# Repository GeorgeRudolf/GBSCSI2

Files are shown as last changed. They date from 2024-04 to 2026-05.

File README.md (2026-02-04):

# GBSCSI2
Affordable SCSI Disk Emulator - upgrade over the original GBSCSI

NOTE: Above all, these boards were initially designed as a hack to satisfy my own personal needs. With that said, they've been tested fairly extensively. Please read this entire README.

Herein are the design files for all variants of GBSCSI2 in KiCad 7 format, being migrated to KiCad 9. The hardware in this repository is licensed CERN OHL-S V2, the full terms of which can be found at https://ohwr.org/cern_ohl_s_v2.pdf and https://ohwr.org/cern_ohl_s_v2.txt.

With thanks to [The Decromancer](https://decromancer.ca/) for sponsoring this project; wohali, tr0n, compu85, sabur and luigi30 for testing; and the rest of UHF for their continued enthusiasm and support. Also to [Rabbit Hole Computing](https://www.rabbitholecomputing.com/) for their continued maintenance of the ZuluSCSI firmware that makes these boards complete, and further testing and collaboration on this project.

# HOW TO:
1. Buy board from decromancer or [Emmy Bear Retro](https://retro.emmybear.shop)
2. It arrives at your doorstep ready to use

OR

1. Get assembled boards using the files in this repository
2. Solder header of your choice
3. (Except for RP2040 version, or if ordering Pico from JLC) Solder RPi Pico - use Pico-W if you want DaynaPORT capabilities for a Mac
4. Go to https://github.com/ZuluSCSI/ZuluSCSI-firmware and grab the Pico/Pico_DaynaPORT version of the latest release and flash to the board by connecting via USB while holding BOOTSEL (or toggling the boot dip switch for RP2040)

# The (very important) details:

1. GBSCSI2 is being moved to a revised hierarchical design that allows for modularity and ease of customization, while maintaining uniformity. The whole project is considered WIP - this warning will be removed once things are tested. Previous versions have been moved to an archive folder. More about them below.

2. The archived Wide SCSI variants are BROKEN. They're incomplete and not usable. 
Rabbit Hole Computing has forked these designs, corrected their flaws and finished the implementation in a manner compatible with standard ZuluSCSI firmware. This fork is now available at https://github.com/ZuluSCSI/ZuluSCSI-Ultra-Wide-OSHW-RP2350B.

3. The variants tagged "untested" are exactly that. I've never personally made boards from them. Use at your own risk.

4. For changes and errata, see the relevant files in the repo.

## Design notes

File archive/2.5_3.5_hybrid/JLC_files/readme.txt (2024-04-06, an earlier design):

JLC RPi Pico pricing is less than ideal - when presented with checkboxes for each component type, you can uncheck the Pico and install your own when boards arrive. Or, leave checked and enjoy the commodity of having them assemble it for you for a few extra bucks.

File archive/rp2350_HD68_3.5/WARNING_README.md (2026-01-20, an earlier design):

This design is incomplete and not usable. Do not manufacture boards from it.

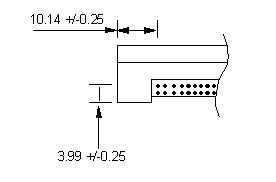
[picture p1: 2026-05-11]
CAD/25mec1.gif

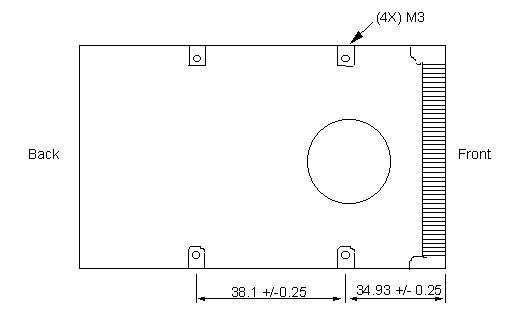
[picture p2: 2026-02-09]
CAD/wds2mec2.gif

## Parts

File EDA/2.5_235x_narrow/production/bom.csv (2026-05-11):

Designator | Footprint | Quantity | Value | LCSC Part #
C1, C4 | 0603 | 2 | 4.7μF | C19666
C10, C27, C5 | 0402 | 3 | 4.7μF | C23733
C11, C13, C14, C15, C16, C17, C18, C19, C28, C6, C8, C9 | 0402 | 12 | 100nF | C307331
C12 | 0402 | 1 | 1μF | C52923
C2, C3 | 0402 | 2 | 15pF | C1548
C20, C35 | 1206 | 2 | 47μF | C96123
C21 | 0603 | 1 | 12pF | C38523
C22, C23, C24, C25, C26, C32, C33 | 0603 | 7 | 100nF | C14663
C29, C30, C7 | 0603 | 3 | 10μF | C96446
C31, C34 | 0603 | 2 | 1μF | C15849
D1, D2, D3, D4 | D_SOD-123 | 4 | 1N5819 | C82544
D5 | 0603 | 1 | YELLOW | C72038
F1, F2 | 0805 | 2 | 1A | C468888
FID1 | Fiducial_0.5mm_Mask1mm | 1 | Fiducial | N/A
J1 | PinHeader_2x25-2_P2.00mm_straddle | 1 | SCSI_50-2P_2mm | N/A
J1.1 | IDC-Header_2x25_P2.54mm_Horizontal | 1 | SCSI_50P_2.54mm | N/A
J2 | TF01A | 1 | TF003 | C5155563
J3 | USB_C_Receptacle_HRO_TYPE-C-31-M-12 | 1 | GCT-4105 | C2927038
J4 | JST_SH_SM03B-SRSS-TB_1x03-1MP_P1.00mm_Horizontal | 1 | SM03B-SRSS-TB | C160403
J4.1 | PinHeader_1x04_P2.54mm_Vertical | 1 | Conn_01x04 | N/A
J5 | PinHeader_1x04_P2.54mm_Horizontal | 1 | Conn_01x04 | N/A
J6 | PinHeader_1x02_P2.54mm_Vertical | 1 | Conn_01x02 | N/A
JP1, JP2 | PinHeader_2x01_P2.54mm_Vertical | 2 | Jumper_2_Open | N/A
L1 | L_Abracon_AOTA-B2016 | 1 | 3.3μH | C42411119
L2 | 1008 | 1 | 1μH | C5832356
M1 | RPi_RM2 | 1 | ~ | N/A
Q1, Q10, Q11, Q12, Q13, Q14, Q15, Q16, Q17, Q18, Q2, Q3, Q4, Q5, Q6, Q7, Q8, Q9 | SOT-23 | 18 | AO3401A | C15127
R1, R4 | 0402 | 2 | 1kΩ | C11702
R10, R11, R12, R18, R19, R20, R21, R22, R29, R5, R6, R7, R8, R9 | 0603 | 14 | 4.7kΩ | C23162
R13, R14, R17, R26, R27, R28, R30, R55 | 0603 | 8 | 1kΩ | C21190
R15, R16, R3 | 0402 | 3 | 22Ω | C25092
R2 | 0402 | 1 | 4.7kΩ | C25900
R23, R24 | 0402 | 2 | 5.1kΩ | C25905
R25, R31, R32, R33, R34, R35, R36, R37, R38, R39, R40, R41, R42, R43, R44, R45, R46, R47, R48 | 0603 | 19 | 110Ω | C22781
R49, R54 | 0402 | 2 | 10kΩ | C25744
R50 | 0402 | 1 | 442kΩ | C5101
R51 | 0402 | 1 | 100kΩ | C25741
R52 | 0603 | 1 | 0Ω | C21189
R53 | 0603 | 1 | ~ | N/A
R56 | 0402 | 1 | 470Ω
SW1 | SW_DIP_SPSTx04_Slide_6.7x11.72mm_W8.61mm_P2.54mm_LowProfile | 1 | SW_DIP_x04 | C5160841
U1 | RP2350-QFN-60-1EP_7x7_P0.4mm_EP3.4x3.4mm_ThermalVias | 1 | RP235x_60QFN | C41378174
U10 | SOT-223-3_TabPin2 | 1 | AZ1117-2.85 | C14791
U2 | SOIC-8_5.23x5.23mm_P1.27mm | 1 | W25Q128JVS | C97521
U3 | SOT-23-6 | 1 | USB TVS | C2827654
U4, U5 | SSOP-20_5.3x7.2mm_P0.65mm | 2 | 74LVTH245 | C2652121
U6, U7 | TSSOP-14_4.4x5mm_P0.65mm | 2 | 74LVTH125 | C7042
U8 | SOT-23-5 | 1 | SN74AHC1G125DBVR | C7468
U9 | SOT-23-5 | 1 | TLV62569DBV | C141836
Y1 | Crystal_SMD_3225-4Pin_3.2x2.5mm | 1 | 12MHz | C20625731

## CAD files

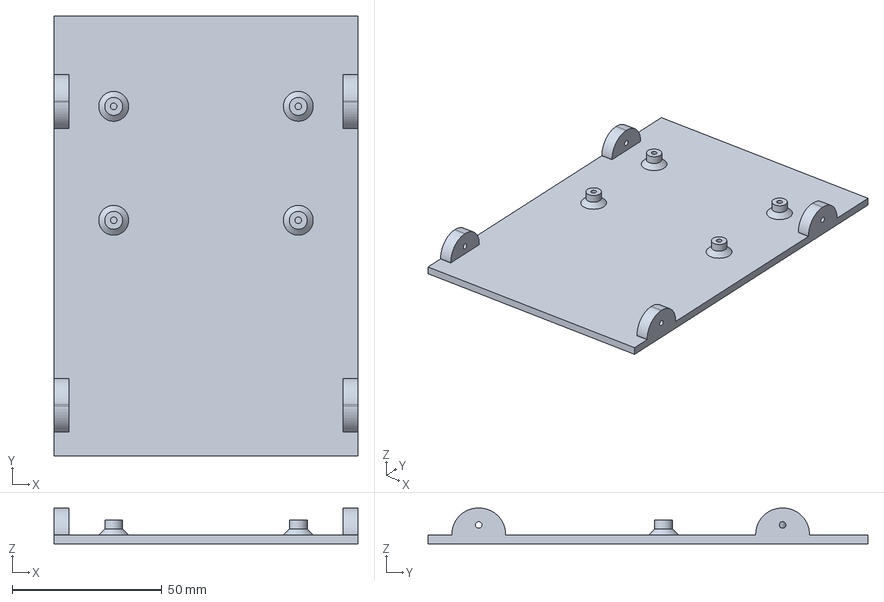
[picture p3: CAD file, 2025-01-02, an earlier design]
archive/2.5_3.5_hybrid/CAD/FreeCAD/GBSCSI2_OS.FCStd
101.7 x 147.0 x 12.0 mm

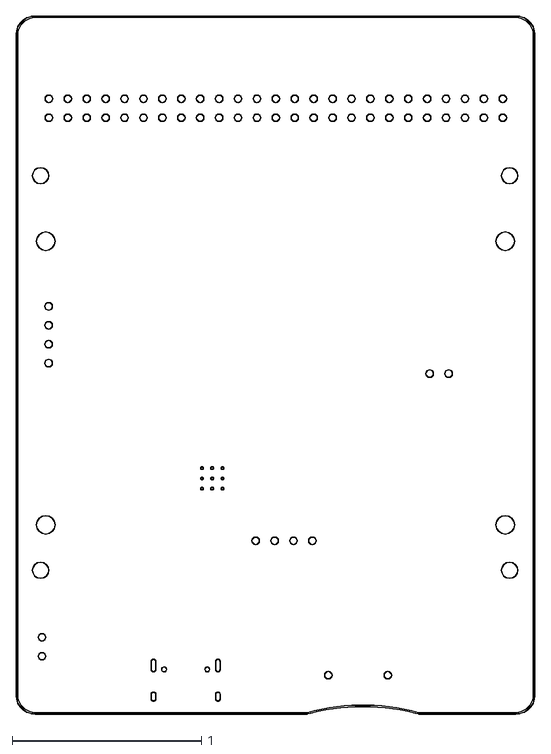
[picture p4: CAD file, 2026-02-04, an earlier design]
archive/rp2350_2.5_3.5_narrow/gbscsi2-Edge_Cuts.dxf
2.74 x 3.69

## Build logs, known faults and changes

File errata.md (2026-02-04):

1. v1.0b Hybrid and v1.0 RP2040 boards have the wrong pad deleted for keying pin on 2.5" header - should be 17 instead of 21.

Patch: Do not install/cut pin 17.

Change: Connector rekeyed.

2. Buck converter for 3.3V has too high of a VIN for the combined drops of all diodes in the 5V chain.

Patch: Lower Vf diodes can (and were) substituted as partial mitigation. Users with other needs would need to investigate their own solutions, potentially using an LM1117-3.3V regulator or similar.

Change: Redesign pending. (Jan/26)

3. Feb. 04 2026> Change: Migrated project to from-scratch redesign.

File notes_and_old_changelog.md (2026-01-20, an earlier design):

# Notes:
1. GBSCSI2 (as of January 2026) does not support powering from TERMPWR in systems with low Vtt. Use the 4-pin connector, with a Molex pigtail if necessary. Examples of machines which may present low Vtt are compact Macs, where TERMPWR is derived from the main 5V rail thru a 1N4001 diode (One can try to mitigate this by replacing the 1N4001 with a Schottky diode of lower Vf).
This exhibits a large forward voltage and may fail to meet SCSI spec. GBSCSI2 is designed with cost and power efficiency in mind, and as such, uses a cheap buck DC-DC converter to supply the board with 3.3V. Minimum input voltage as per the manufacturer's datasheet is 4.2V.
Given the forward voltage of the diodes on GBSCSI2 (about 450mV), and Vtt at TERMPWR having a minimum of 4.25V, this may leave the regulator receiving only about 3.8V. Feeding the regulator less than 4.0V has been reported to result in erratic operation. In that scenario, please power
the board from a separate 5V source as described above. If there is enough demand, a variant employing an LDO can be created. This would, however, waste more power, which is undesirable in laptops - the main use case for which this board was created. A redesign is pending.

2. JLC will no longer solder the Pico for you using their Economic PCBA service. The Standard PCB service has a $25 setup fee. Their Pico prices are not great anyway, so you might as well also solder that on your own, if you wanna save as much as possible. 

# Changelog:
1. PDN redesigned on Hybrid V1.0 boards to provide better ground return paths. V1.0b implements the change and is the first publicly available variant in this repository.

2. v1.0c Hybrid changed to 1.0d, for ground plane repour around 2.5" header keying change in 1.0c. Other 2.5" boards also changed, but as they don't have published gerbers, their revision numbers weren't changed.
Schottky diodes changed in BoM for all boards (JLC P/N C8598 to C82544). This is due to C8598 typically exhibiting too high of a forward voltage.

3. RP2350 boards have been tested by Rabbit Hole Computing's (makers of ZuluSCSI) Alex Perez (many thanks!) and are officially released as validated builds. Suitable firmware available at https://github.com/ZuluSCSI/ZuluSCSI-firmware/releases/tag/v2024.10.11-pico2-beta

4. A Fast Wide SCSI variant was been designed, and abandoned for the entirety of 2025. As of January 2026, the files in the repository are unusable for practical purposes as-is. A redesign is pending.

5. Further changes will no longer be logged here, but in commit history alone. Critical errata will be listed separately.

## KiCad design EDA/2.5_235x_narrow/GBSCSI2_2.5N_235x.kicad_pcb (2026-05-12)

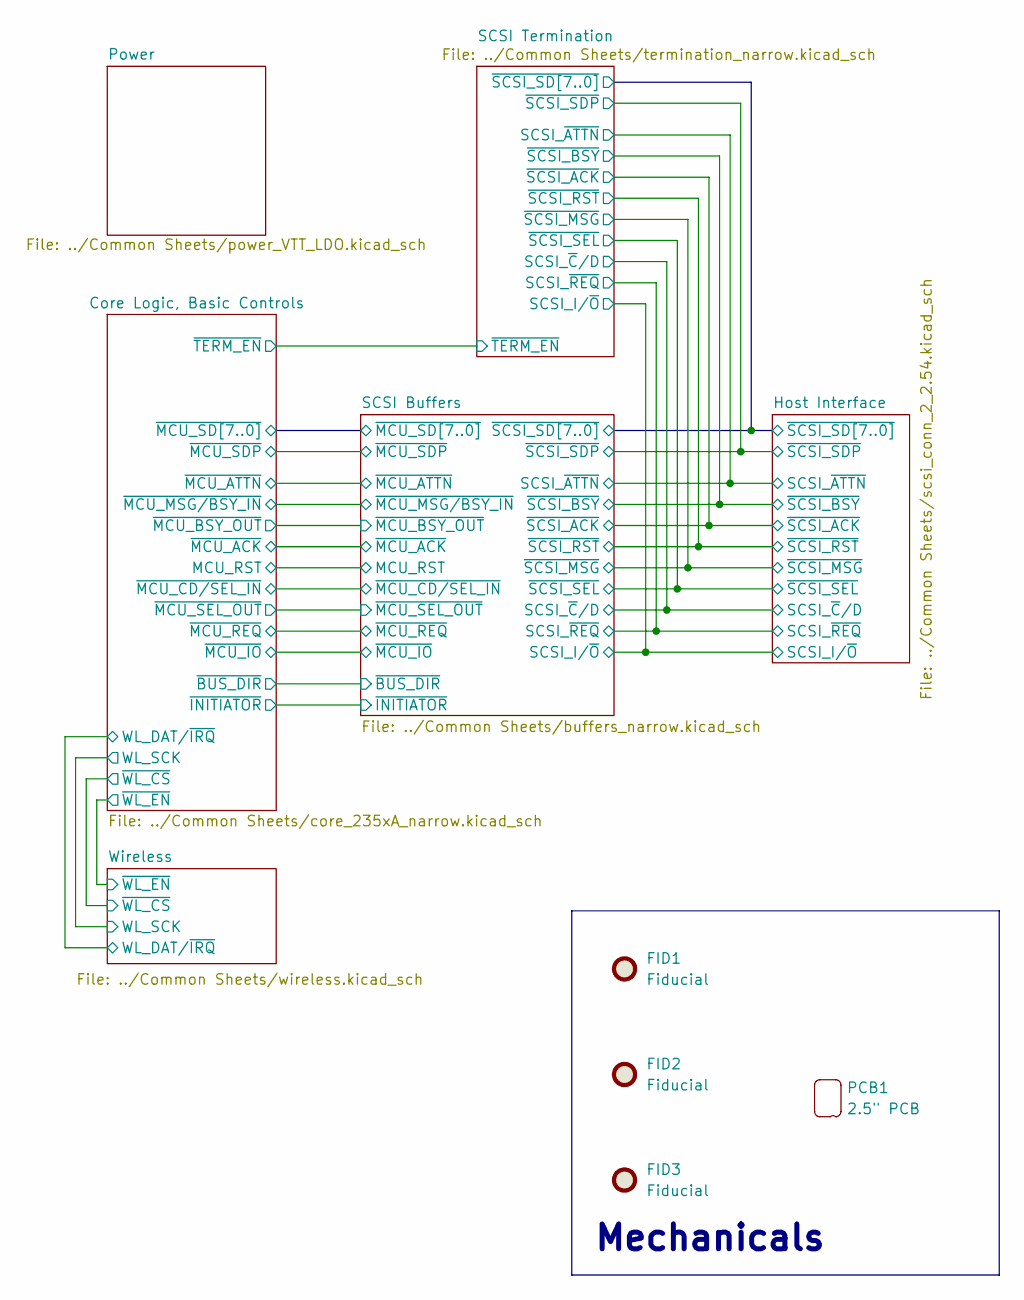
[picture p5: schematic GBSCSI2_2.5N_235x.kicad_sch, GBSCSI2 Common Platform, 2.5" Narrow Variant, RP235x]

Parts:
FID1, FID2, FID3: Fiducial; Fiducial_0.5mm_Mask1mm; LCSC N/A
PCB1: 2.5" PCB; GBSCSI2_2.5_PCB

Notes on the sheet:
Mechanicals

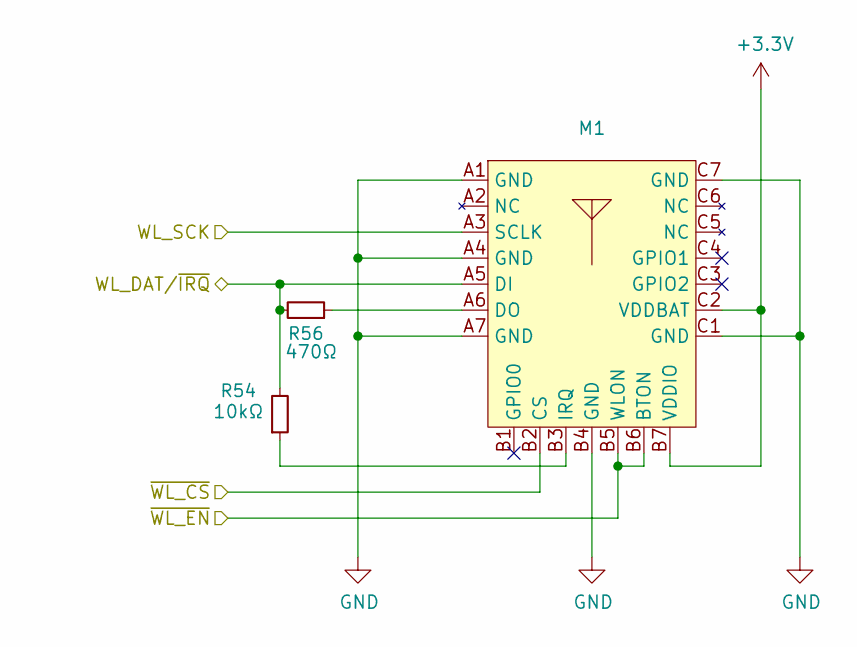
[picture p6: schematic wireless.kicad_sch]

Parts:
M1: RPi_RM2; LCSC N/A
R54: 10kΩ; R_0402_1005Metric; LCSC C25744
R56: 470Ω; R_0402_1005Metric

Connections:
+3.3V: M1.B7 (VDDIO), M1.C2 (VDDBAT); also elsewhere on the board
/Core Logic, Basic Controls/WL_DAT/~IRQ: M1.A5 (DI), R54.2, R56.2; also elsewhere on the board
/Core Logic, Basic Controls/WL_SCK: M1.A3 (SCLK); also elsewhere on the board
/Core Logic, Basic Controls/~WL_CS: M1.B2 (CS); also elsewhere on the board
/Core Logic, Basic Controls/~WL_EN: M1.B5 (WLON), M1.B6 (BTON); also elsewhere on the board
GND: M1.A1 (GND), M1.A4 (GND), M1.A7 (GND), M1.B4 (GND), M1.C1 (GND), M1.C7 (GND); also elsewhere on the board
unnamed: M1.A6 (DO), R56.1
unnamed: M1.B3 (IRQ), R54.1

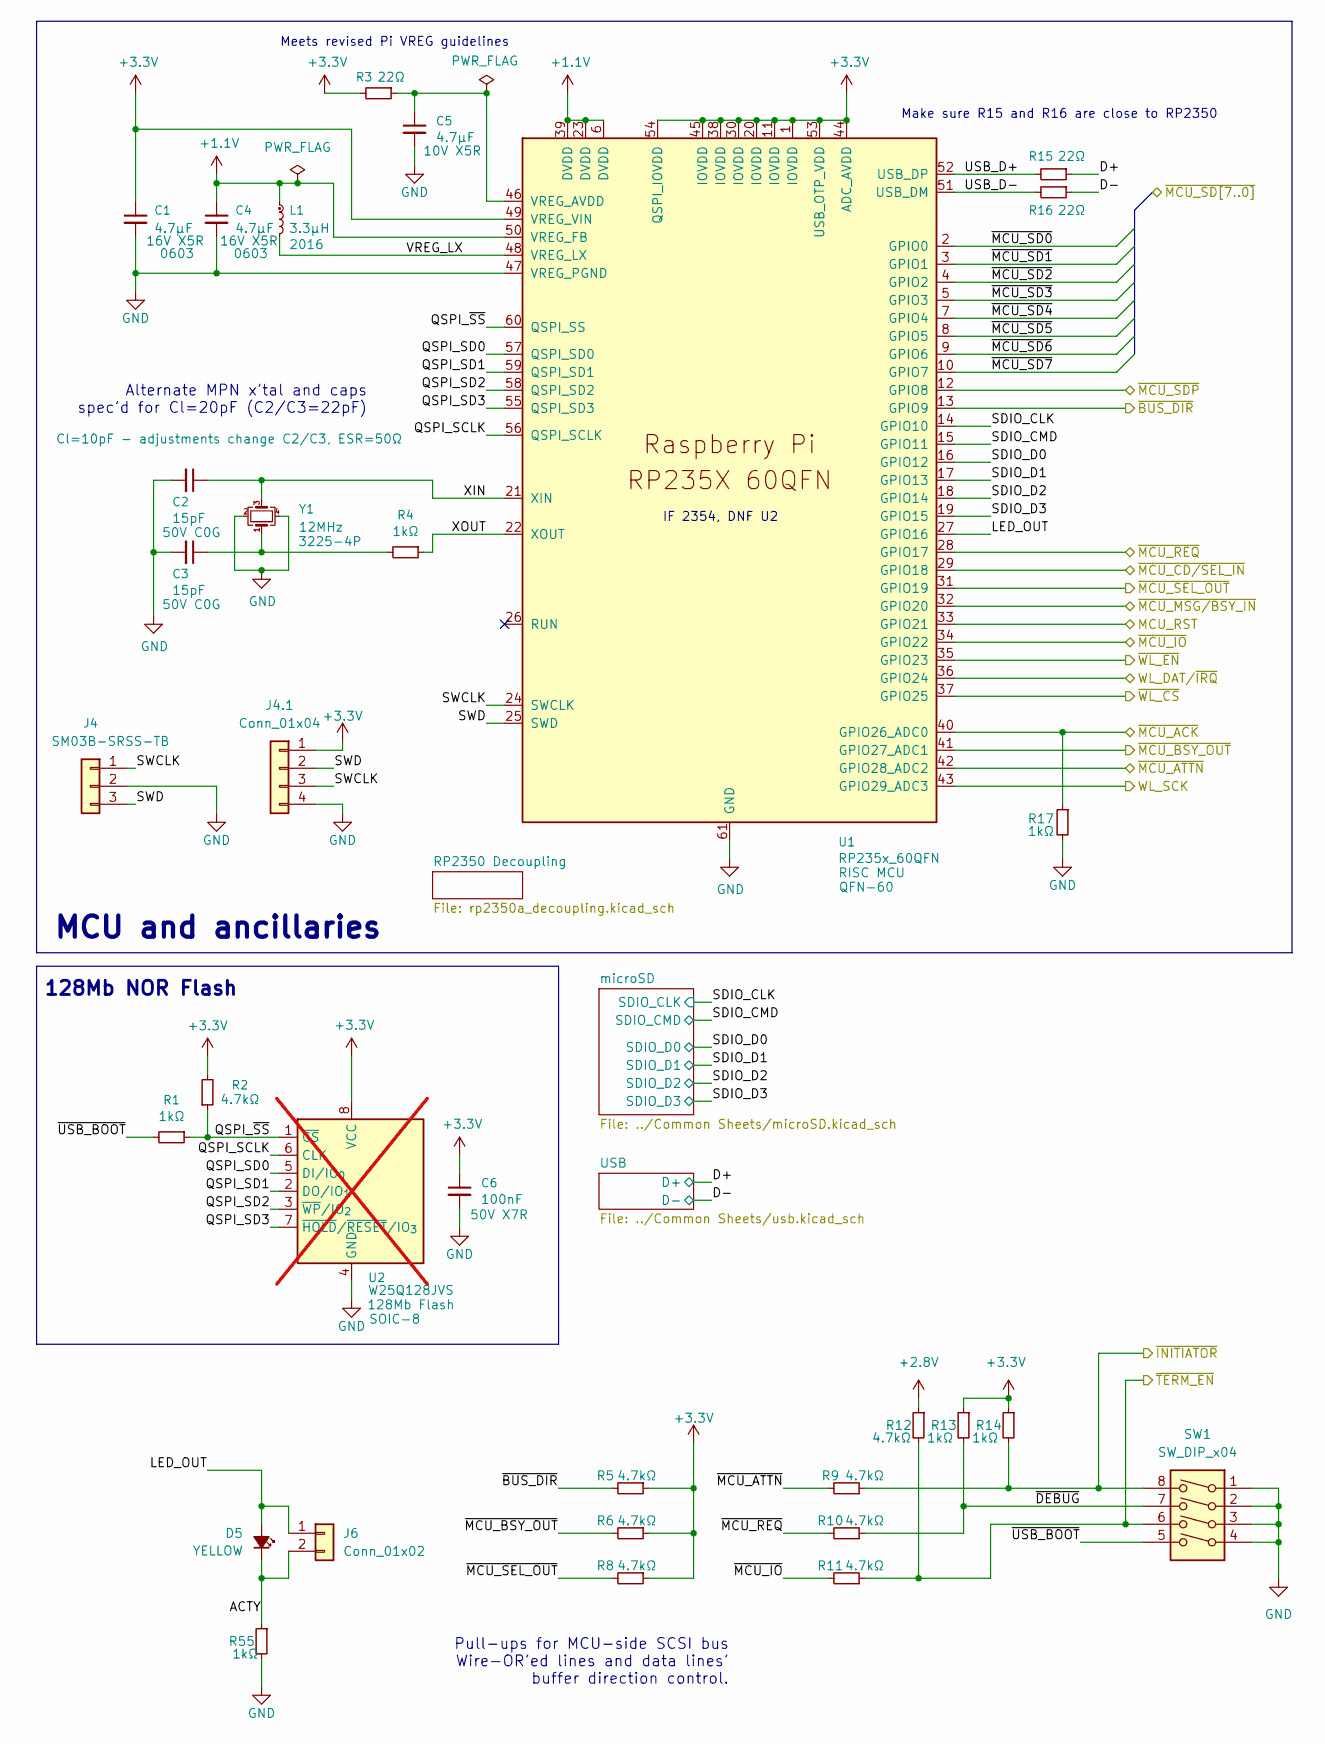
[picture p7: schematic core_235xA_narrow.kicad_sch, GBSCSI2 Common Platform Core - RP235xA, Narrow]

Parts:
C1, C4: 4.7μF; C_0603_1608Metric; LCSC C19666
C2, C3: 15pF; C_0402_1005Metric; LCSC C1548
C5: 4.7μF; C_0402_1005Metric; LCSC C23733
C6: 100nF; C_0402_1005Metric; LCSC C307331
D5: YELLOW; LED_0603_1608Metric; LCSC C72038
J4: SM03B-SRSS-TB; JST_SH_SM03B-SRSS-TB_1x03-1MP_P1.00mm_Horizontal; LCSC C160403
J4.1: Conn_01x04; PinHeader_1x04_P2.54mm_Vertical; LCSC N/A
J6: Conn_01x02; PinHeader_1x02_P2.54mm_Vertical; LCSC N/A
L1: 3.3μH; L_Abracon_AOTA-B2016; LCSC C42411119
R1, R4: 1kΩ; R_0402_1005Metric; LCSC C11702
R2: 4.7kΩ; R_0402_1005Metric; LCSC C25900
R3, R15, R16: 22Ω; R_0402_1005Metric; LCSC C25092
R5, R6, R8, R9, R10, R11, R12: 4.7kΩ; R_0603_1608Metric; LCSC C23162
R13, R14, R17, R55: 1kΩ; R_0603_1608Metric; LCSC C21190
SW1: SW_DIP_x04; SW_DIP_SPSTx04_Slide_6.7x11.72mm_W8.61mm_P2.54mm_LowProfile; LCSC C5160841
U1: RP235x_60QFN; RP2350-QFN-60-1EP_7x7_P0.4mm_EP3.4x3.4mm_ThermalVias; LCSC C41378174
U2: W25Q128JVS; SOIC-8_5.3x5.3mm_P1.27mm; LCSC C97521; not fitted
Y1: 12MHz; Crystal_SMD_3225-4Pin_3.2x2.5mm; LCSC C20625731

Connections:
+1.1V: C4.1, L1.1, U1.6 (DVDD), U1.23 (DVDD), U1.39 (DVDD), U1.50 (VREG_FB); also elsewhere on the board
+2.8V: R12.1; also elsewhere on the board
+3.3V: C1.1, C6.1, J4.1.1, R2.2, R3.2, R5.1, R6.1, R8.1, R13.1, R14.1, U1.1 (IOVDD), U1.11 (IOVDD), U1.20 (IOVDD), U1.30 (IOVDD), U1.38 (IOVDD), U1.44 (ADC_AVDD), U1.45 (IOVDD), U1.49 (VREG_VIN), U1.53 (USB_OTP_VDD), U1.54 (QSPI_IOVDD), U2.8 (VCC); also elsewhere on the board
/Core Logic, Basic Controls/ACTY: D5.1 (K), J6.2, R55.1
/Core Logic, Basic Controls/D+: R15.1; also elsewhere on the board
/Core Logic, Basic Controls/D-: R16.1; also elsewhere on the board
/Core Logic, Basic Controls/LED_OUT: D5.2 (A), J6.1, U1.27 (GPIO16)
/Core Logic, Basic Controls/MCU_RST: U1.33 (GPIO21); also elsewhere on the board
/Core Logic, Basic Controls/QSPI_SCLK: U1.56 (QSPI_SCLK), U2.6 (CLK)
/Core Logic, Basic Controls/QSPI_SD0: U1.57 (QSPI_SD0), U2.5 (DI/IO_{0})
/Core Logic, Basic Controls/QSPI_SD1: U1.59 (QSPI_SD1), U2.2 (DO/IO_{1})
/Core Logic, Basic Controls/QSPI_SD2: U1.58 (QSPI_SD2), U2.3 (~WP/IO_{2})
/Core Logic, Basic Controls/QSPI_SD3: U1.55 (QSPI_SD3), U2.7 (~HOLD/~RESET/IO_{3})
/Core Logic, Basic Controls/QSPI_~SS: R1.1, R2.1, U1.60 (QSPI_SS), U2.1 (~CS)
/Core Logic, Basic Controls/SDIO_CLK: U1.14 (GPIO10); also elsewhere on the board
/Core Logic, Basic Controls/SDIO_CMD: U1.15 (GPIO11); also elsewhere on the board
/Core Logic, Basic Controls/SDIO_D0: U1.16 (GPIO12); also elsewhere on the board
/Core Logic, Basic Controls/SDIO_D1: U1.17 (GPIO13); also elsewhere on the board
/Core Logic, Basic Controls/SDIO_D2: U1.18 (GPIO14); also elsewhere on the board
/Core Logic, Basic Controls/SDIO_D3: U1.19 (GPIO15); also elsewhere on the board
/Core Logic, Basic Controls/SWCLK: J4.1, J4.1.3, U1.24 (SWCLK)
/Core Logic, Basic Controls/SWD: J4.3, J4.1.2, U1.25 (SWD)
/Core Logic, Basic Controls/USB_D+: R15.2, U1.52 (USB_DP)
/Core Logic, Basic Controls/USB_D-: R16.2, U1.51 (USB_DM)
/Core Logic, Basic Controls/VREG_LX: L1.2, U1.48 (VREG_LX)
/Core Logic, Basic Controls/WL_DAT/~IRQ: U1.36 (GPIO24); also elsewhere on the board
/Core Logic, Basic Controls/WL_SCK: U1.43 (GPIO29_ADC3); also elsewhere on the board
/Core Logic, Basic Controls/XIN: C2.1, U1.21 (XIN), Y1.3
/Core Logic, Basic Controls/XOUT: R4.1, U1.22 (XOUT)
/Core Logic, Basic Controls/~BUS_DIR: R5.2, U1.13 (GPIO9); also elsewhere on the board
/Core Logic, Basic Controls/~DEBUG: R10.1, R13.2, SW1.7
/Core Logic, Basic Controls/~INITIATOR: R9.1, R14.2, SW1.8; also elsewhere on the board
/Core Logic, Basic Controls/~MCU_ACK: R17.1, U1.40 (GPIO26_ADC0); also elsewhere on the board
/Core Logic, Basic Controls/~MCU_ATTN: R9.2, U1.42 (GPIO28_ADC2); also elsewhere on the board
/Core Logic, Basic Controls/~MCU_BSY_OUT: R6.2, U1.41 (GPIO27_ADC1); also elsewhere on the board
/Core Logic, Basic Controls/~MCU_CD/SEL_IN: U1.29 (GPIO18); also elsewhere on the board
/Core Logic, Basic Controls/~MCU_IO: R11.2, U1.34 (GPIO22); also elsewhere on the board
/Core Logic, Basic Controls/~MCU_MSG/BSY_IN: U1.32 (GPIO20); also elsewhere on the board
/Core Logic, Basic Controls/~MCU_REQ: R10.2, U1.28 (GPIO17); also elsewhere on the board
/Core Logic, Basic Controls/~MCU_SD0: U1.2 (GPIO0); also elsewhere on the board
/Core Logic, Basic Controls/~MCU_SD1: U1.3 (GPIO1); also elsewhere on the board
/Core Logic, Basic Controls/~MCU_SD2: U1.4 (GPIO2); also elsewhere on the board
/Core Logic, Basic Controls/~MCU_SD3: U1.5 (GPIO3); also elsewhere on the board
/Core Logic, Basic Controls/~MCU_SD4: U1.7 (GPIO4); also elsewhere on the board
/Core Logic, Basic Controls/~MCU_SD5: U1.8 (GPIO5); also elsewhere on the board
/Core Logic, Basic Controls/~MCU_SD6: U1.9 (GPIO6); also elsewhere on the board
/Core Logic, Basic Controls/~MCU_SD7: U1.10 (GPIO7); also elsewhere on the board
/Core Logic, Basic Controls/~MCU_SDP: U1.12 (GPIO8); also elsewhere on the board
/Core Logic, Basic Controls/~MCU_SEL_OUT: R8.2, U1.31 (GPIO19); also elsewhere on the board
/Core Logic, Basic Controls/~TERM_EN: R11.1, R12.2, SW1.6; also elsewhere on the board
/Core Logic, Basic Controls/~USB_BOOT: R1.2, SW1.5
/Core Logic, Basic Controls/~WL_CS: U1.37 (GPIO25); also elsewhere on the board
/Core Logic, Basic Controls/~WL_EN: U1.35 (GPIO23); also elsewhere on the board
GND: C1.2, C2.2, C3.2, C4.2, C5.2, C6.2, J4.2, J4.1.4, R17.2, R55.2, SW1.1, SW1.2, SW1.3, SW1.4, U1.47 (VREG_PGND), U1.61 (GND), U2.4 (GND), Y1.2, Y1.4; also elsewhere on the board
unnamed: C3.1, R4.2, Y1.1
unnamed: C5.1, R3.1, U1.46 (VREG_AVDD)

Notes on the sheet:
128Mb NOR Flash
Alternate MPN x'tal and caps spec'd for Cl=20pF (C2/C3=22pF)
Pull-ups for MCU-side SCSI bus Wire-OR'ed lines and data lines' buffer direction control.
IF 2354, DNF U2
MCU and ancillaries
Make sure R15 and R16 are close to RP2350
Meets revised Pi VREG guidelines

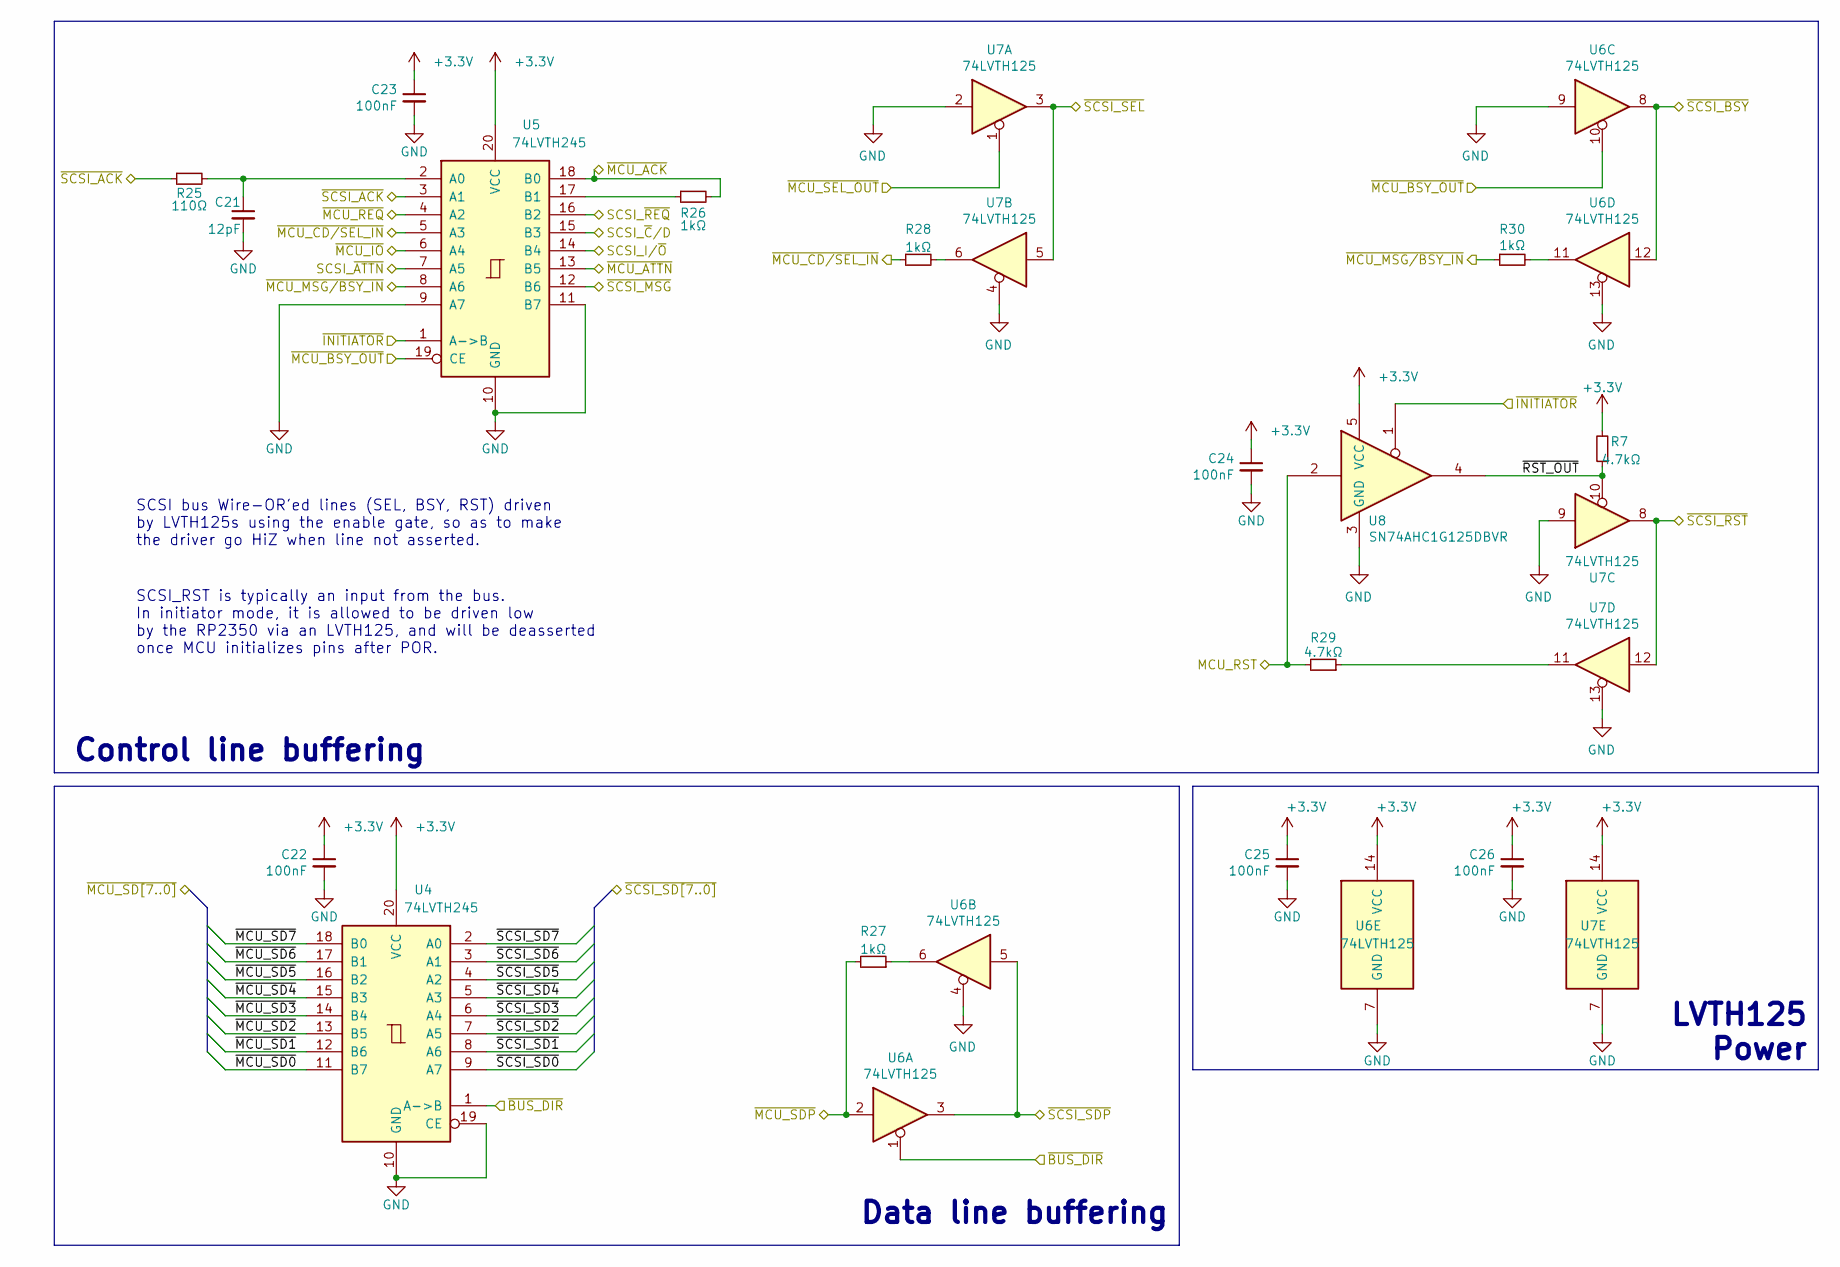
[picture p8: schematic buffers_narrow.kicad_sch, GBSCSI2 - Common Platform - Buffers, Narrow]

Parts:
C21: 12pF; C_0603_1608Metric; LCSC C38523
C22, C23, C24, C25, C26: 100nF; C_0603_1608Metric; LCSC C14663
R7, R29: 4.7kΩ; R_0603_1608Metric; LCSC C23162
R25: 110Ω; R_0603_1608Metric; LCSC C22781
R26, R27, R28, R30: 1kΩ; R_0603_1608Metric; LCSC C21190
U4, U5: 74LVTH245; SSOP-20_5.3x7.2mm_P0.65mm; LCSC C2652121
U6, U7: 74LVTH125; TSSOP-14_4.4x5mm_P0.65mm; LCSC C7042
U8: SN74AHC1G125DBVR; SOT-23-5; LCSC C7468

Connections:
+3.3V: C22.1, C23.1, C24.1, C25.1, C26.1, R7.2, U4.20 (VCC), U5.20 (VCC), U6.14 (VCC), U7.14 (VCC), U8.5 (VCC); also elsewhere on the board
/Core Logic, Basic Controls/MCU_RST: R29.2, U8.2; also elsewhere on the board
/Core Logic, Basic Controls/~BUS_DIR: U4.1 (A->B), U6.1; also elsewhere on the board
/Core Logic, Basic Controls/~INITIATOR: U5.1 (A->B), U8.1; also elsewhere on the board
/Core Logic, Basic Controls/~MCU_ACK: R26.2, U5.18 (B0); also elsewhere on the board
/Core Logic, Basic Controls/~MCU_ATTN: U5.13 (B5); also elsewhere on the board
/Core Logic, Basic Controls/~MCU_BSY_OUT: U5.19 (CE), U6.10; also elsewhere on the board
/Core Logic, Basic Controls/~MCU_CD/SEL_IN: R28.1, U5.5 (A3); also elsewhere on the board
/Core Logic, Basic Controls/~MCU_IO: U5.6 (A4); also elsewhere on the board
/Core Logic, Basic Controls/~MCU_MSG/BSY_IN: R30.1, U5.8 (A6); also elsewhere on the board
/Core Logic, Basic Controls/~MCU_REQ: U5.4 (A2); also elsewhere on the board
/Core Logic, Basic Controls/~MCU_SD0: U4.11 (B7); also elsewhere on the board
/Core Logic, Basic Controls/~MCU_SD1: U4.12 (B6); also elsewhere on the board
/Core Logic, Basic Controls/~MCU_SD2: U4.13 (B5); also elsewhere on the board
/Core Logic, Basic Controls/~MCU_SD3: U4.14 (B4); also elsewhere on the board
/Core Logic, Basic Controls/~MCU_SD4: U4.15 (B3); also elsewhere on the board
/Core Logic, Basic Controls/~MCU_SD5: U4.16 (B2); also elsewhere on the board
/Core Logic, Basic Controls/~MCU_SD6: U4.17 (B1); also elsewhere on the board
/Core Logic, Basic Controls/~MCU_SD7: U4.18 (B0); also elsewhere on the board
/Core Logic, Basic Controls/~MCU_SDP: R27.2, U6.2; also elsewhere on the board
/Core Logic, Basic Controls/~MCU_SEL_OUT: U7.1; also elsewhere on the board
/Host Interface/SCSI_I/~O: U5.14 (B4); also elsewhere on the board
/Host Interface/SCSI_~ATTN: U5.7 (A5); also elsewhere on the board
/Host Interface/SCSI_~C/D: U5.15 (B3); also elsewhere on the board
/Host Interface/SCSI_~REQ: U5.16 (B2); also elsewhere on the board
/Host Interface/~SCSI_ACK: R25.1, U5.3 (A1); also elsewhere on the board
/Host Interface/~SCSI_BSY: U6.8, U6.12; also elsewhere on the board
/Host Interface/~SCSI_MSG: U5.12 (B6); also elsewhere on the board
/Host Interface/~SCSI_RST: U7.8, U7.12; also elsewhere on the board
/Host Interface/~SCSI_SD0: U4.9 (A7); also elsewhere on the board
/Host Interface/~SCSI_SD1: U4.8 (A6); also elsewhere on the board
/Host Interface/~SCSI_SD2: U4.7 (A5); also elsewhere on the board
/Host Interface/~SCSI_SD3: U4.6 (A4); also elsewhere on the board
/Host Interface/~SCSI_SD4: U4.5 (A3); also elsewhere on the board
/Host Interface/~SCSI_SD5: U4.4 (A2); also elsewhere on the board
/Host Interface/~SCSI_SD6: U4.3 (A1); also elsewhere on the board
/Host Interface/~SCSI_SD7: U4.2 (A0); also elsewhere on the board
/Host Interface/~SCSI_SDP: U6.3, U6.5; also elsewhere on the board
/Host Interface/~SCSI_SEL: U7.3, U7.5; also elsewhere on the board
/SCSI Buffers/~RST_OUT: R7.1, U7.10, U8.4
GND: C21.2, C22.2, C23.2, C24.2, C25.2, C26.2, U4.10 (GND), U4.19 (CE), U5.9 (A7), U5.10 (GND), U5.11 (B7), U6.4, U6.7 (GND), U6.9, U6.13, U7.2, U7.4, U7.7 (GND), U7.9, U7.13, U8.3 (GND); also elsewhere on the board
unnamed: R27.1, U6.6
unnamed: R28.2, U7.6
unnamed: R29.1, U7.11
unnamed: R30.2, U6.11
unnamed: C21.1, R25.2, U5.2 (A0)
unnamed: R26.1, U5.17 (B1)

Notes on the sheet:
Control line buffering
SCSI_RST is typically an input from the bus. In initiator mode, it is allowed to be driven low by the RP2350 via an LVTH125, and will be deasserted once MCU initializes pins after POR.
LVTH125 Power
SCSI bus Wire-OR'ed lines (SEL, BSY, RST) driven by LVTH125s using the enable gate, so as to make the driver go HiZ when line not asserted.
Data line buffering

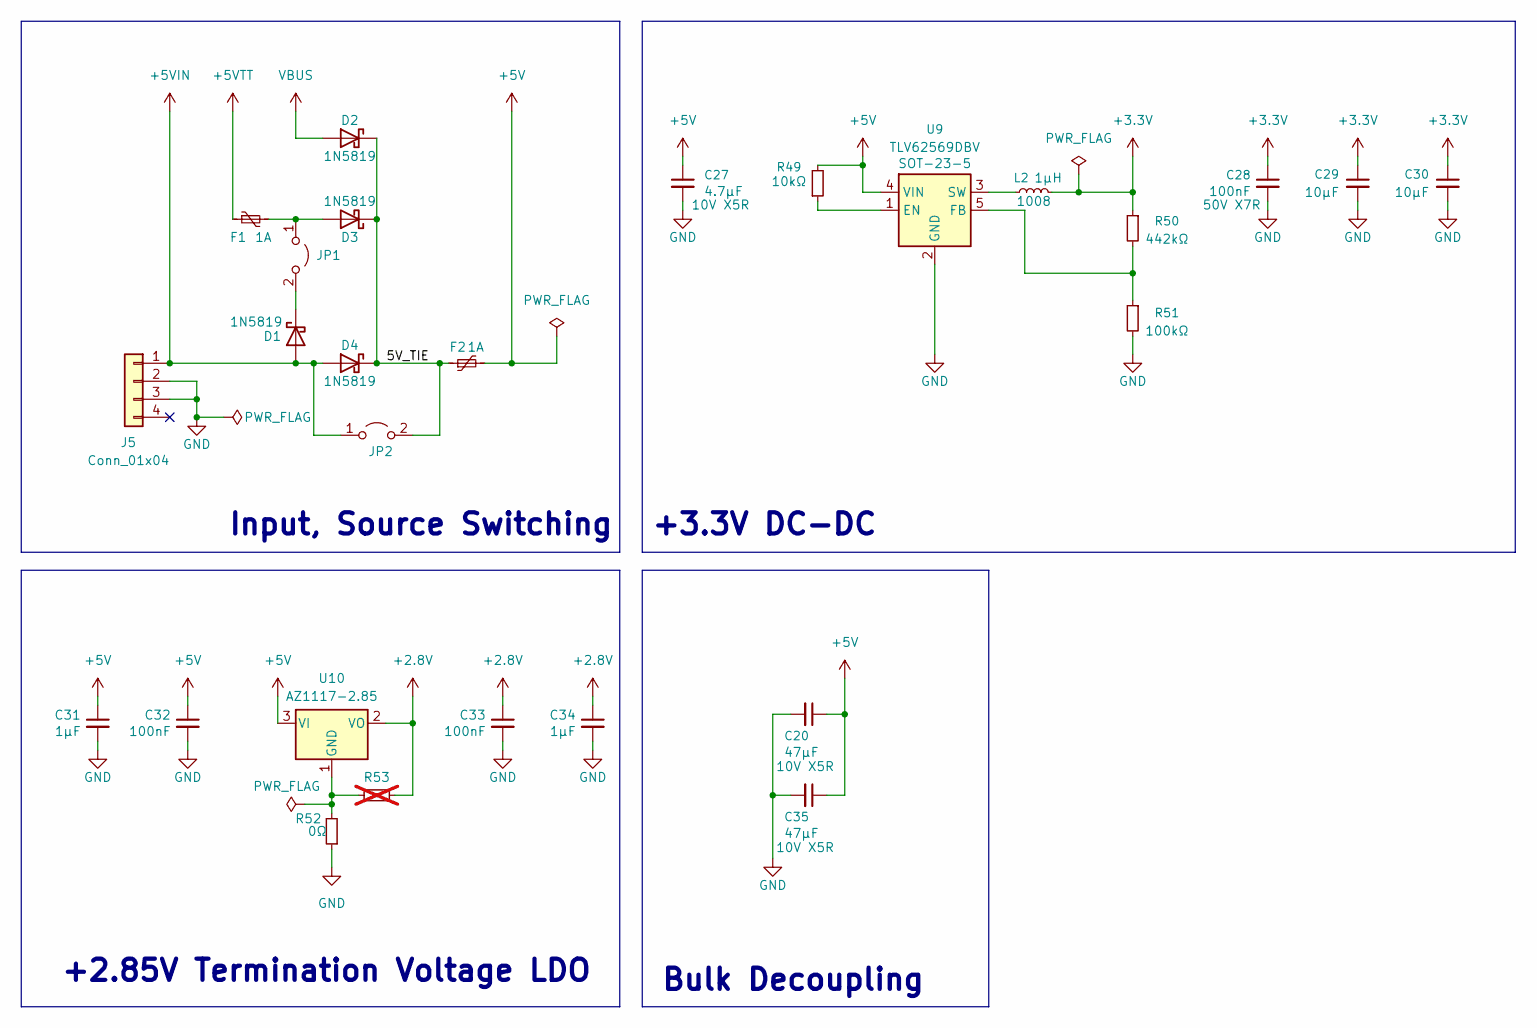
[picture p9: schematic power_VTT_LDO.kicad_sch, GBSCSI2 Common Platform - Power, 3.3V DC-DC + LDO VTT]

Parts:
C20, C35: 47μF; C_1206_3216Metric; LCSC C96123
C27: 4.7μF; C_0402_1005Metric; LCSC C23733
C28: 100nF; C_0402_1005Metric; LCSC C307331
C29, C30: 10μF; C_0603_1608Metric; LCSC C96446
C31, C34: 1μF; C_0603_1608Metric; LCSC C15849
C32, C33: 100nF; C_0603_1608Metric; LCSC C14663
D1, D2, D3, D4: 1N5819; D_SOD-123; LCSC C191023
F1, F2: 1A; Fuse_0805_2012Metric; LCSC C468888
J5: Conn_01x04; PinHeader_1x04_P2.54mm_Horizontal; LCSC N/A
JP1, JP2: Jumper_2_Open; PinHeader_2x01_P2.54mm_Vertical; LCSC N/A
L2: 1μH; L_1008_2520Metric; LCSC C5832356
R49: 10kΩ; R_0402_1005Metric; LCSC C25744
R50: 442kΩ; R_0402_1005Metric; LCSC C5101
R51: 100kΩ; R_0402_1005Metric; LCSC C25741
R52: 0Ω; R_0603_1608Metric; LCSC C21189
R53: R_0603_1608Metric; LCSC N/A; not fitted
U9: TLV62569DBV; SOT-23-5; LCSC C141836
U10: AZ1117-2.85; SOT-223-3_TabPin2; LCSC C14791

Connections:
+2.8V: C33.1, C34.1, R53.2, U10.2 (VO); also elsewhere on the board
+3.3V: C28.1, C29.1, C30.1, L2.2, R50.1; also elsewhere on the board
+5V: C20.1, C27.1, C31.1, C32.1, C35.1, F2.2, R49.2, U9.4 (VIN), U10.3 (VI)
+5VIN: D1.2 (A), D4.2 (A), J5.1, JP2.1 (A); also elsewhere on the board
+5VTT: F1.1; also elsewhere on the board
/Power/5V_TIE: D2.1 (K), D3.1 (K), D4.1 (K), F2.1, JP2.2 (B)
GND: C20.2, C27.2, C28.2, C29.2, C30.2, C31.2, C32.2, C33.2, C34.2, C35.2, J5.2, J5.3, R51.2, R52.1, U9.2 (GND); also elsewhere on the board
unnamed: D1.1 (K), JP1.2 (B)
unnamed: D3.2 (A), F1.2, JP1.1 (A)
unnamed: R49.1, U9.1 (EN)
unnamed: R50.2, R51.1, U9.5 (FB)
unnamed: L2.1, U9.3 (SW)
unnamed: R52.2, R53.1, U10.1 (GND)
VBUS: D2.2 (A); also elsewhere on the board

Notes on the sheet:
+2.85V Termination Voltage LDO
+3.3V DC-DC
Bulk Decoupling
Input, Source Switching

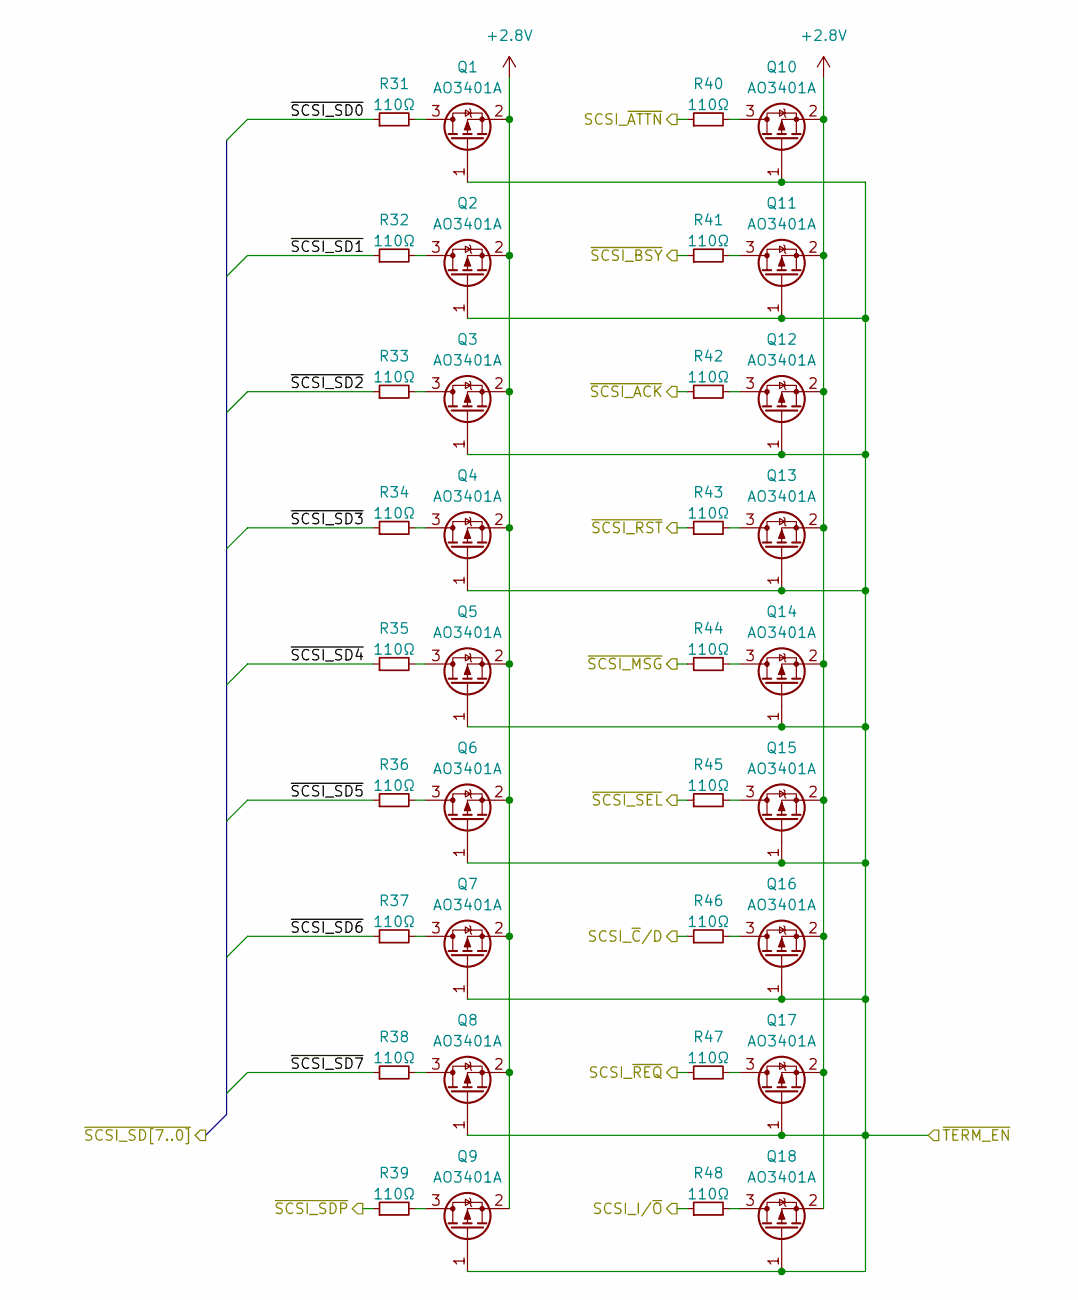
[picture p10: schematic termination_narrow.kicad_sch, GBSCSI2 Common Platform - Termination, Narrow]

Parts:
Q1, Q2, Q3, Q4, Q5, Q6, Q7, Q8, Q9, Q10, Q11, Q12, Q13, Q14, Q15, Q16, Q17, Q18: AO3401A; SOT-23; LCSC C15127
R31, R32, R33, R34, R35, R36, R37, R38, R39, R40, R41, R42, R43, R44, R45, R46, R47, R48: 110Ω; R_0603_1608Metric; LCSC C22781

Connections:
+2.8V: Q1.2 (S), Q2.2 (S), Q3.2 (S), Q4.2 (S), Q5.2 (S), Q6.2 (S), Q7.2 (S), Q8.2 (S), Q9.2 (S), Q10.2 (S), Q11.2 (S), Q12.2 (S), Q13.2 (S), Q14.2 (S), Q15.2 (S), Q16.2 (S), Q17.2 (S), Q18.2 (S); also elsewhere on the board
/Core Logic, Basic Controls/~TERM_EN: Q1.1 (G), Q2.1 (G), Q3.1 (G), Q4.1 (G), Q5.1 (G), Q6.1 (G), Q7.1 (G), Q8.1 (G), Q9.1 (G), Q10.1 (G), Q11.1 (G), Q12.1 (G), Q13.1 (G), Q14.1 (G), Q15.1 (G), Q16.1 (G), Q17.1 (G), Q18.1 (G); also elsewhere on the board
/Host Interface/SCSI_I/~O: R48.1; also elsewhere on the board
/Host Interface/SCSI_~ATTN: R40.1; also elsewhere on the board
/Host Interface/SCSI_~C/D: R46.1; also elsewhere on the board
/Host Interface/SCSI_~REQ: R47.1; also elsewhere on the board
/Host Interface/~SCSI_ACK: R42.1; also elsewhere on the board
/Host Interface/~SCSI_BSY: R41.1; also elsewhere on the board
/Host Interface/~SCSI_MSG: R44.1; also elsewhere on the board
/Host Interface/~SCSI_RST: R43.1; also elsewhere on the board
/Host Interface/~SCSI_SD0: R31.1; also elsewhere on the board
/Host Interface/~SCSI_SD1: R32.1; also elsewhere on the board
/Host Interface/~SCSI_SD2: R33.1; also elsewhere on the board
/Host Interface/~SCSI_SD3: R34.1; also elsewhere on the board
/Host Interface/~SCSI_SD4: R35.1; also elsewhere on the board
/Host Interface/~SCSI_SD5: R36.1; also elsewhere on the board
/Host Interface/~SCSI_SD6: R37.1; also elsewhere on the board
/Host Interface/~SCSI_SD7: R38.1; also elsewhere on the board
/Host Interface/~SCSI_SDP: R39.1; also elsewhere on the board
/Host Interface/~SCSI_SEL: R45.1; also elsewhere on the board
unnamed: Q1.3 (D), R31.2
unnamed: Q2.3 (D), R32.2
unnamed: Q3.3 (D), R33.2
unnamed: Q4.3 (D), R34.2
unnamed: Q5.3 (D), R35.2
unnamed: Q6.3 (D), R36.2
unnamed: Q7.3 (D), R37.2
unnamed: Q8.3 (D), R38.2
unnamed: Q9.3 (D), R39.2
unnamed: Q10.3 (D), R40.2
unnamed: Q11.3 (D), R41.2
unnamed: Q12.3 (D), R42.2
unnamed: Q13.3 (D), R43.2
unnamed: Q14.3 (D), R44.2
unnamed: Q15.3 (D), R45.2
unnamed: Q16.3 (D), R46.2
unnamed: Q17.3 (D), R47.2
unnamed: Q18.3 (D), R48.2

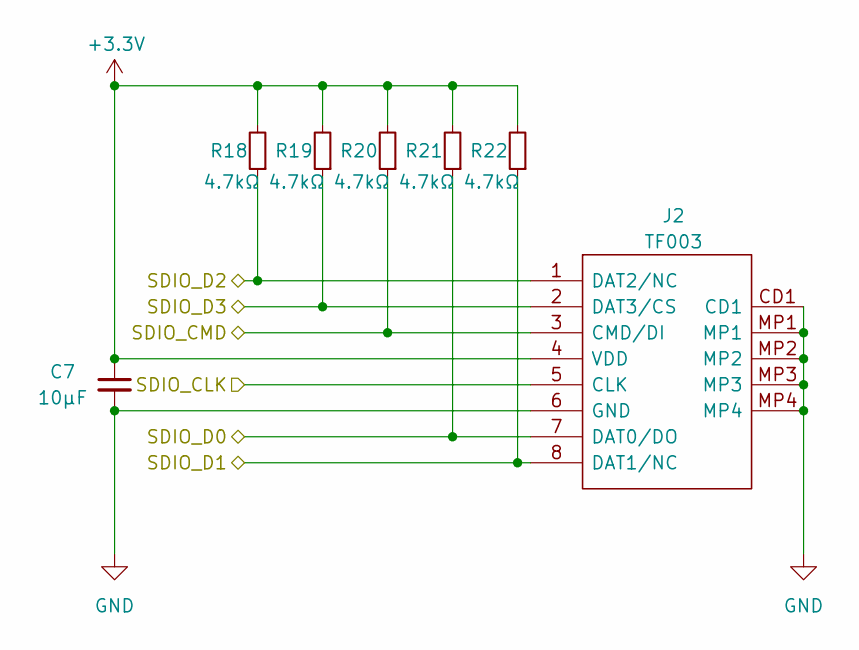
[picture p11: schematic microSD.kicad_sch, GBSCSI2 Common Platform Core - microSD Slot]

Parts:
C7: 10μF; C_0603_1608Metric; LCSC C96446
J2: TF003; TF01A; LCSC C5155563
R18, R19, R20, R21, R22: 4.7kΩ; R_0603_1608Metric; LCSC C23162

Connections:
+3.3V: C7.1, J2.4 (VDD), R18.2, R19.2, R20.2, R21.2, R22.2; also elsewhere on the board
/Core Logic, Basic Controls/SDIO_CLK: J2.5 (CLK); also elsewhere on the board
/Core Logic, Basic Controls/SDIO_CMD: J2.3 (CMD/DI), R20.1; also elsewhere on the board
/Core Logic, Basic Controls/SDIO_D0: J2.7 (DAT0/DO), R21.1; also elsewhere on the board
/Core Logic, Basic Controls/SDIO_D1: J2.8 (DAT1/NC), R22.1; also elsewhere on the board
/Core Logic, Basic Controls/SDIO_D2: J2.1 (DAT2/NC), R18.1; also elsewhere on the board
/Core Logic, Basic Controls/SDIO_D3: J2.2 (DAT3/CS), R19.1; also elsewhere on the board
GND: C7.2, J2.6 (GND), J2.CD1, J2.MP1, J2.MP2, J2.MP3, J2.MP4; also elsewhere on the board

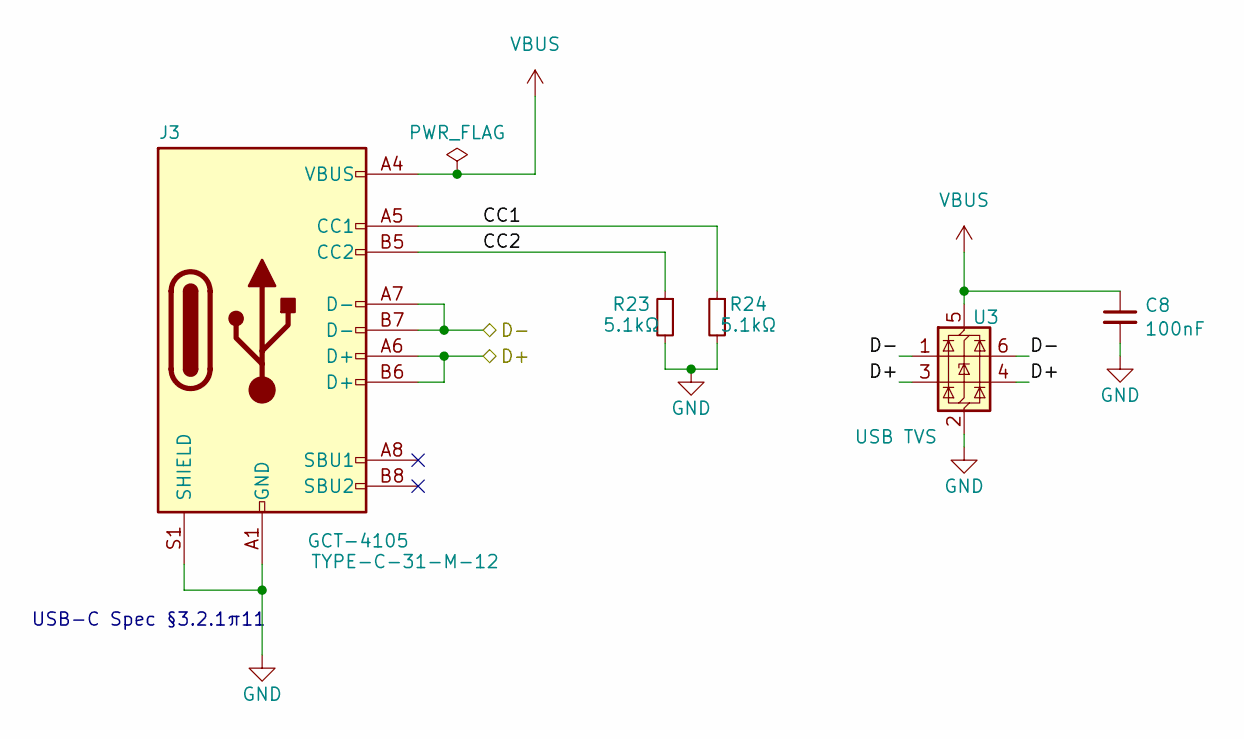
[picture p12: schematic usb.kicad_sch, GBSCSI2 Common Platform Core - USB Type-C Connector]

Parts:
C8: 100nF; C_0402_1005Metric; LCSC C307331
J3: GCT-4105; USB_C_Receptacle_HRO_TYPE-C-31-M-12; LCSC C2927038
R23, R24: 5.1kΩ; R_0402_1005Metric; LCSC C25905
U3: USB TVS; SOT-23-6; LCSC C2827654

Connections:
/Core Logic, Basic Controls/D+: J3.A6 (D+), J3.B6 (D+), U3.3 (I/O2), U3.4 (I/O2); also elsewhere on the board
/Core Logic, Basic Controls/D-: J3.A7 (D-), J3.B7 (D-), U3.1 (I/O1), U3.6 (I/O1); also elsewhere on the board
/Core Logic, Basic Controls/USB/CC1: J3.A5 (CC1), R24.1
/Core Logic, Basic Controls/USB/CC2: J3.B5 (CC2), R23.1
GND: C8.2, J3.A1 (GND), J3.A12 (GND), J3.B1 (GND), J3.B12 (GND), J3.S1 (SHIELD), R23.2, R24.2, U3.2 (GND); also elsewhere on the board
VBUS: C8.1, J3.A4 (VBUS), J3.A9 (VBUS), J3.B4 (VBUS), J3.B9 (VBUS), U3.5 (VBUS); also elsewhere on the board

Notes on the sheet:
USB-C Spec §3.2.1¶11

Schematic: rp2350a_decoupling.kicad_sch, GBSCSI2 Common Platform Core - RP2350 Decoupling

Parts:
C9, C11, C13, C14, C15, C16, C17, C18, C19: 100nF; C_0402_1005Metric; LCSC C307331
C10: 4.7μF; C_0402_1005Metric; LCSC C23733
C12: 1μF; C_0402_1005Metric; LCSC C52923

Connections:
+1.1V: C9.1, C10.1, C11.1; also elsewhere on the board
+3.3V: C12.1, C13.1, C14.1, C15.1, C16.1, C17.1, C18.1, C19.1; also elsewhere on the board
GND: C9.2, C10.2, C11.2, C12.2, C13.2, C14.2, C15.2, C16.2, C17.2, C18.2, C19.2; also elsewhere on the board

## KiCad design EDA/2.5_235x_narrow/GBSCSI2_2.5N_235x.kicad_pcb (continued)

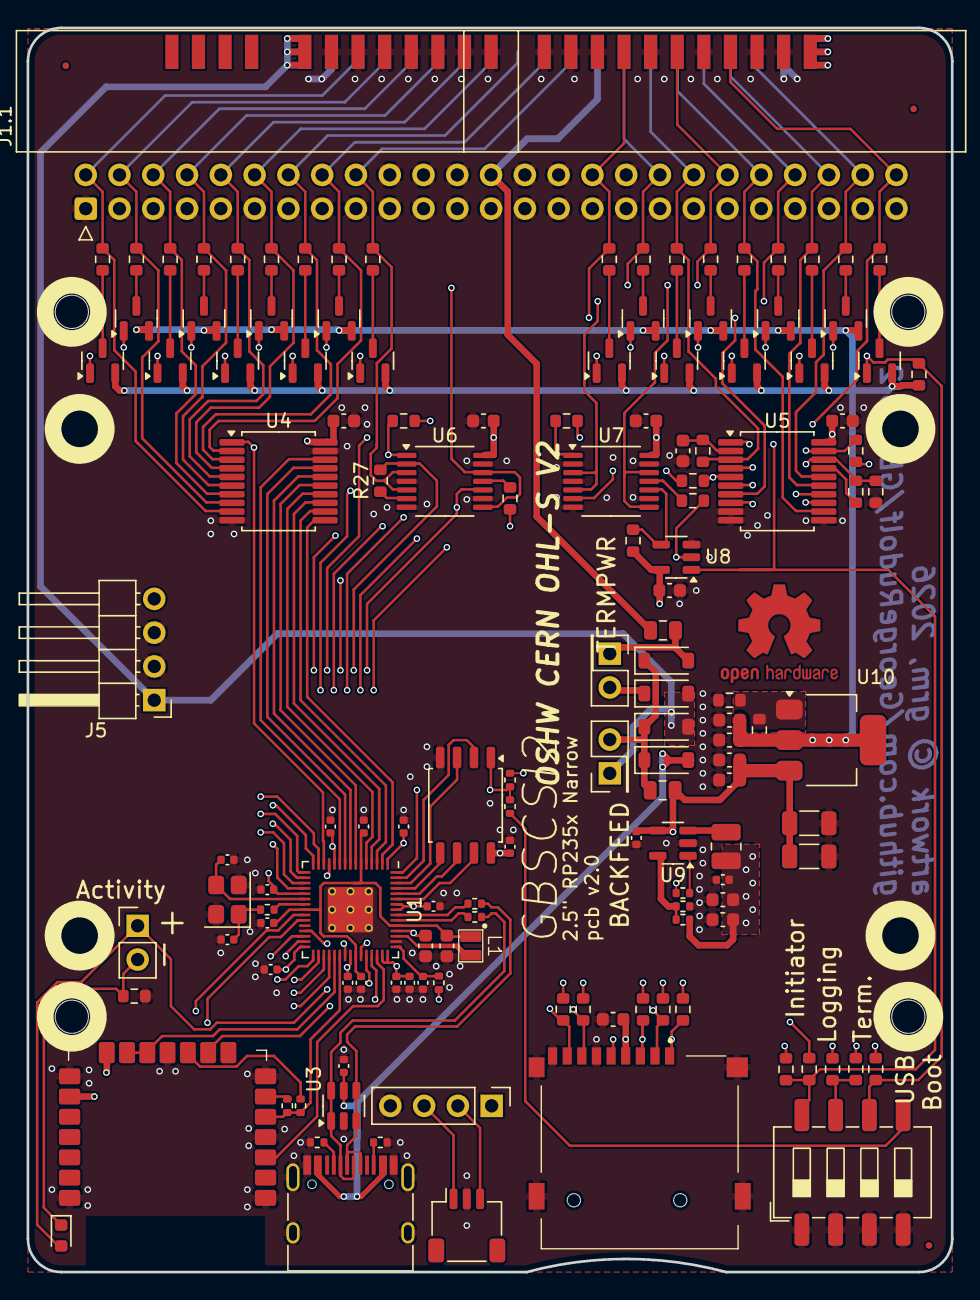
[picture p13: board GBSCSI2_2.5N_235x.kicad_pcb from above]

Board: 4 copper layers, 69.5 x 93.5 mm, 145 parts (0 on the bottom side), 114 nets.

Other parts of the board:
J1: SCSI_50-2P_2mm; PinHeader_2x25-2_P2.00mm_straddle
J1.1: SCSI_50P_2.54mm; IDC-Header_2x25_P2.54mm_Horizontal

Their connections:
+5VIN: J1.1, J1.2, J1.39, J1.40; also elsewhere on the board
+5VTT: J1.24, J1.1.26; also elsewhere on the board
/Host Interface/SCSI_I/~O: J1.33, J1.1.50; also elsewhere on the board
/Host Interface/SCSI_~ATTN: J1.25, J1.1.32; also elsewhere on the board
/Host Interface/SCSI_~C/D: J1.34, J1.1.46; also elsewhere on the board
/Host Interface/SCSI_~REQ: J1.36, J1.1.48; also elsewhere on the board
/Host Interface/~SCSI_ACK: J1.28, J1.1.38; also elsewhere on the board
/Host Interface/~SCSI_BSY: J1.26, J1.1.36; also elsewhere on the board
/Host Interface/~SCSI_MSG: J1.30, J1.1.42; also elsewhere on the board
/Host Interface/~SCSI_RST: J1.29, J1.1.40; also elsewhere on the board
/Host Interface/~SCSI_SD0: J1.6, J1.1.2; also elsewhere on the board
/Host Interface/~SCSI_SD1: J1.8, J1.1.4; also elsewhere on the board
/Host Interface/~SCSI_SD2: J1.10, J1.1.6; also elsewhere on the board
/Host Interface/~SCSI_SD3: J1.12, J1.1.8; also elsewhere on the board
/Host Interface/~SCSI_SD4: J1.14, J1.1.10; also elsewhere on the board
/Host Interface/~SCSI_SD5: J1.16, J1.1.12; also elsewhere on the board
/Host Interface/~SCSI_SD6: J1.18, J1.1.14; also elsewhere on the board
/Host Interface/~SCSI_SD7: J1.20, J1.1.16; also elsewhere on the board
/Host Interface/~SCSI_SDP: J1.22, J1.1.18; also elsewhere on the board
/Host Interface/~SCSI_SEL: J1.32, J1.1.44; also elsewhere on the board
GND: J1.3, J1.4, J1.5, J1.7, J1.9, J1.11, J1.13, J1.15, J1.19, J1.21, J1.23, J1.27, J1.31, J1.35, J1.37, J1.38, J1.1.1, J1.1.3, J1.1.5, J1.1.7, J1.1.9, J1.1.11, J1.1.13, J1.1.15, J1.1.17, J1.1.19, J1.1.20, J1.1.21, J1.1.22, J1.1.23, J1.1.24, J1.1.25, J1.1.27, J1.1.28, J1.1.29, J1.1.30, J1.1.31, J1.1.33, J1.1.34, J1.1.35, J1.1.37, J1.1.39, J1.1.41, J1.1.43, J1.1.45, J1.1.47, J1.1.49; also elsewhere on the board

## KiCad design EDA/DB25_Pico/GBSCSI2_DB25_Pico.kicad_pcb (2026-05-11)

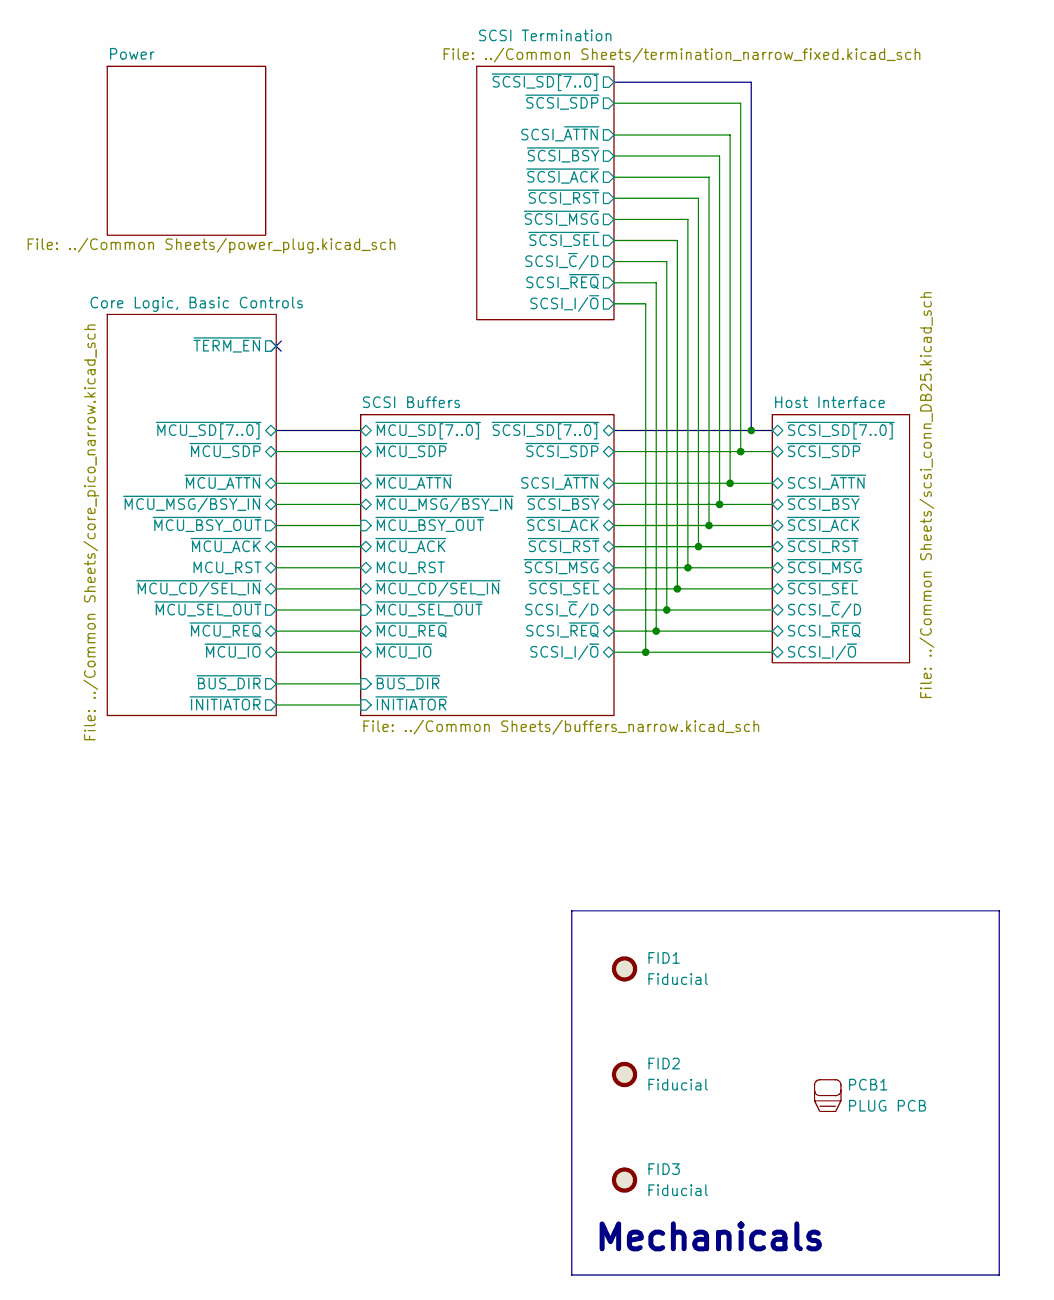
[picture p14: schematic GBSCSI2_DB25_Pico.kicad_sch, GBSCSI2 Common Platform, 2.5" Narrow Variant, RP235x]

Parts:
FID1, FID2, FID3: Fiducial; Fiducial_0.5mm_Mask1mm; LCSC N/A
PCB1: PLUG PCB; GBSCSI2_PLUG_PCB

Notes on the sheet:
Mechanicals

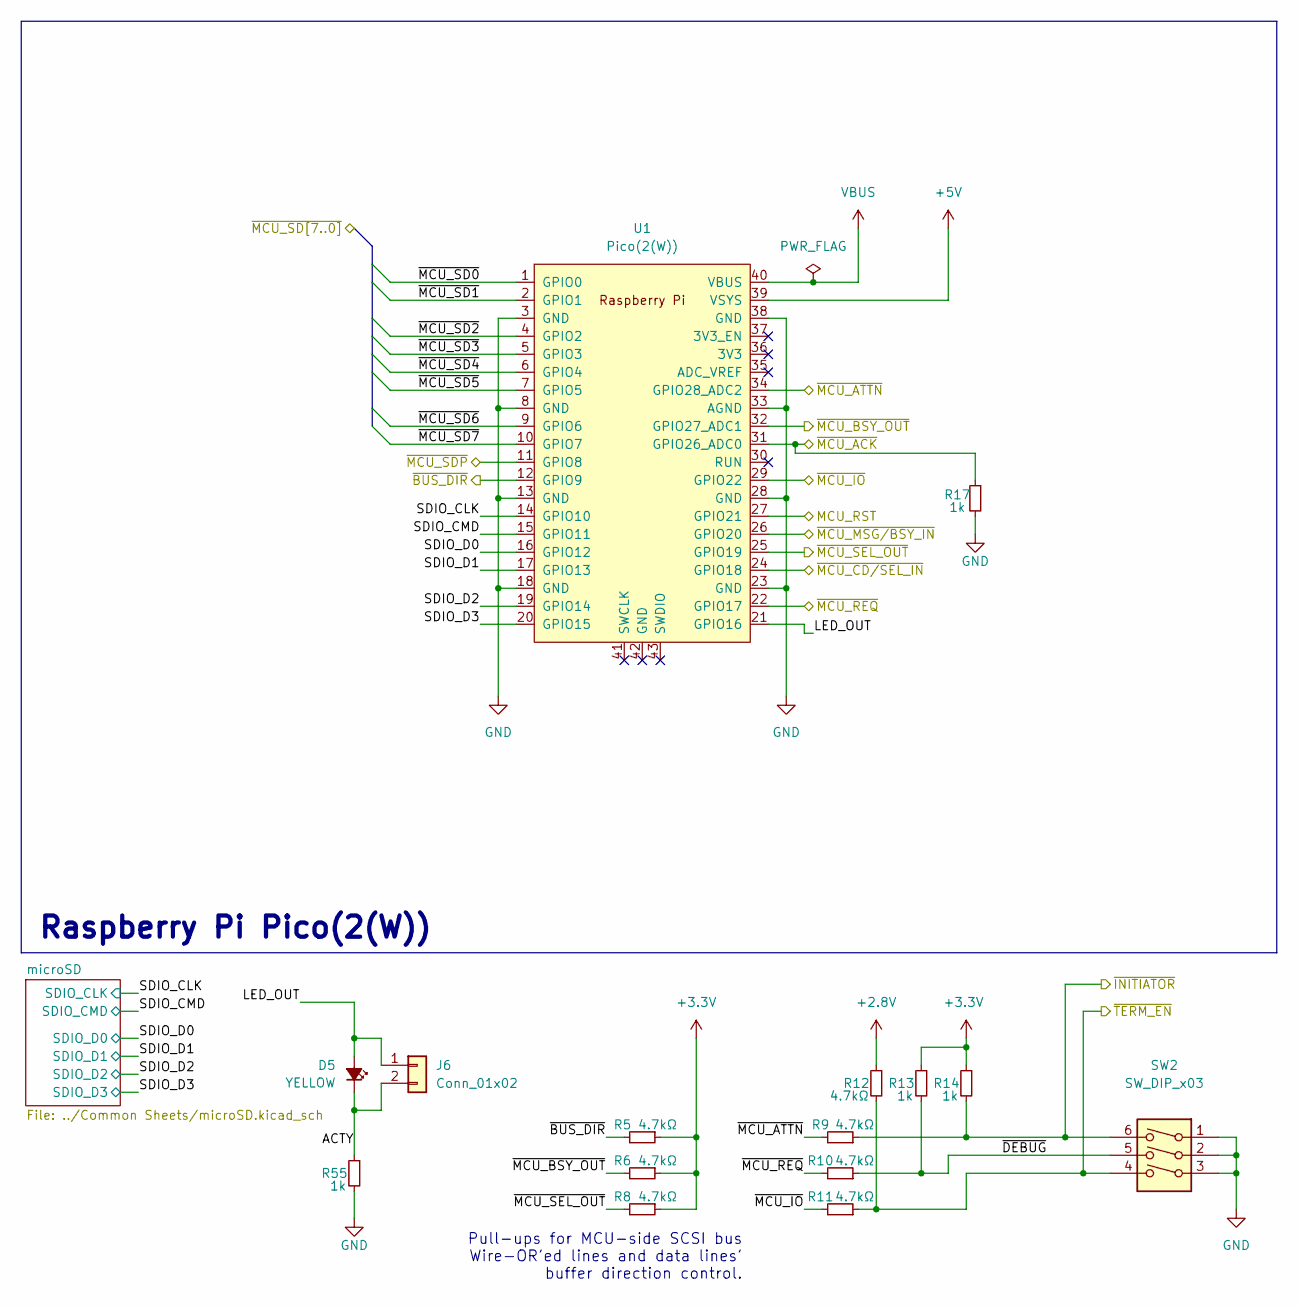
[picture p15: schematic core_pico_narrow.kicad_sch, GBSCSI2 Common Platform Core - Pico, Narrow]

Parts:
D5: YELLOW; LED_0603_1608Metric; LCSC C72038
J6: Conn_01x02; PinHeader_1x02_P2.54mm_Vertical; LCSC N/A
R5, R6, R8, R9, R10, R11, R12: 4.7kΩ; R_0603_1608Metric; LCSC C23162
R13, R14, R17, R55: 1k; R_0603_1608Metric; LCSC C21190
SW2: SW_DIP_x03; SW_DIP_SPSTx03_Slide_6.7x9.18mm_W8.61mm_P2.54mm_LowProfile; LCSC C2842910
U1: Pico(2(W)); RPi_Pico_W_SMD; LCSC C7203003

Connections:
+2.8V: R12.1; also elsewhere on the board
+3.3V: R5.1, R6.1, R8.1, R13.1, R14.1; also elsewhere on the board
+5V: U1.39 (VSYS); also elsewhere on the board
/Core Logic, Basic Controls/ACTY: D5.1 (K), J6.2, R55.1
/Core Logic, Basic Controls/LED_OUT: D5.2 (A), J6.1, U1.21 (GPIO16)
/Core Logic, Basic Controls/MCU_RST: U1.27 (GPIO21); also elsewhere on the board
/Core Logic, Basic Controls/SDIO_CLK: U1.14 (GPIO10); also elsewhere on the board
/Core Logic, Basic Controls/SDIO_CMD: U1.15 (GPIO11); also elsewhere on the board
/Core Logic, Basic Controls/SDIO_D0: U1.16 (GPIO12); also elsewhere on the board
/Core Logic, Basic Controls/SDIO_D1: U1.17 (GPIO13); also elsewhere on the board
/Core Logic, Basic Controls/SDIO_D2: U1.19 (GPIO14); also elsewhere on the board
/Core Logic, Basic Controls/SDIO_D3: U1.20 (GPIO15); also elsewhere on the board
/Core Logic, Basic Controls/~BUS_DIR: R5.2, U1.12 (GPIO9); also elsewhere on the board
/Core Logic, Basic Controls/~DEBUG: R10.1, R13.2, SW2.5
/Core Logic, Basic Controls/~INITIATOR: R9.1, R14.2, SW2.6; also elsewhere on the board
/Core Logic, Basic Controls/~MCU_ACK: R17.1, U1.31 (GPIO26_ADC0); also elsewhere on the board
/Core Logic, Basic Controls/~MCU_ATTN: R9.2, U1.34 (GPIO28_ADC2); also elsewhere on the board
/Core Logic, Basic Controls/~MCU_BSY_OUT: R6.2, U1.32 (GPIO27_ADC1); also elsewhere on the board
/Core Logic, Basic Controls/~MCU_CD/SEL_IN: U1.24 (GPIO18); also elsewhere on the board
/Core Logic, Basic Controls/~MCU_IO: R11.2, U1.29 (GPIO22); also elsewhere on the board
/Core Logic, Basic Controls/~MCU_MSG/BSY_IN: U1.26 (GPIO20); also elsewhere on the board
/Core Logic, Basic Controls/~MCU_REQ: R10.2, U1.22 (GPIO17); also elsewhere on the board
/Core Logic, Basic Controls/~MCU_SD0: U1.1 (GPIO0); also elsewhere on the board
/Core Logic, Basic Controls/~MCU_SD1: U1.2 (GPIO1); also elsewhere on the board
/Core Logic, Basic Controls/~MCU_SD2: U1.4 (GPIO2); also elsewhere on the board
/Core Logic, Basic Controls/~MCU_SD3: U1.5 (GPIO3); also elsewhere on the board
/Core Logic, Basic Controls/~MCU_SD4: U1.6 (GPIO4); also elsewhere on the board
/Core Logic, Basic Controls/~MCU_SD5: U1.7 (GPIO5); also elsewhere on the board
/Core Logic, Basic Controls/~MCU_SD6: U1.9 (GPIO6); also elsewhere on the board
/Core Logic, Basic Controls/~MCU_SD7: U1.10 (GPIO7); also elsewhere on the board
/Core Logic, Basic Controls/~MCU_SDP: U1.11 (GPIO8); also elsewhere on the board
/Core Logic, Basic Controls/~MCU_SEL_OUT: R8.2, U1.25 (GPIO19); also elsewhere on the board
/Core Logic, Basic Controls/~TERM_EN: R11.1, R12.2, SW2.4
GND: R17.2, R55.2, SW2.1, SW2.2, SW2.3, U1.3 (GND), U1.8 (GND), U1.13 (GND), U1.18 (GND), U1.23 (GND), U1.28 (GND), U1.33 (AGND), U1.38 (GND); also elsewhere on the board
VBUS: U1.40 (VBUS); also elsewhere on the board

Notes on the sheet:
Pull-ups for MCU-side SCSI bus Wire-OR'ed lines and data lines' buffer direction control.
Raspberry Pi Pico(2(W))


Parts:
C21: 12pF; C_0603_1608Metric; LCSC C38523
C22, C23, C24, C25, C26: 100nF; C_0603_1608Metric; LCSC C14663
R7, R29: 4.7kΩ; R_0603_1608Metric; LCSC C23162
R25: 110Ω; R_0603_1608Metric; LCSC C22781
R26, R27, R28, R30: 1kΩ; R_0603_1608Metric; LCSC C21190
U4, U5: 74LVTH245; SSOP-20_5.3x7.2mm_P0.65mm; LCSC C2652121
U6, U7: 74LVTH125; TSSOP-14_4.4x5mm_P0.65mm; LCSC C7042
U8: SN74AHC1G125DBVR; SOT-23-5; LCSC C7468

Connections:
+3.3V: C22.1, C23.1, C24.1, C25.1, C26.1, R7.2, U4.20 (VCC), U5.20 (VCC), U6.14 (VCC), U7.14 (VCC), U8.5 (VCC); also elsewhere on the board
/Core Logic, Basic Controls/MCU_RST: R29.2, U8.2; also elsewhere on the board
/Core Logic, Basic Controls/~BUS_DIR: U4.1 (A->B), U6.1; also elsewhere on the board
/Core Logic, Basic Controls/~INITIATOR: U5.1 (A->B), U8.1; also elsewhere on the board
/Core Logic, Basic Controls/~MCU_ACK: R26.2, U5.18 (B0); also elsewhere on the board
/Core Logic, Basic Controls/~MCU_ATTN: U5.13 (B5); also elsewhere on the board
/Core Logic, Basic Controls/~MCU_BSY_OUT: U5.19 (CE), U6.10; also elsewhere on the board
/Core Logic, Basic Controls/~MCU_CD/SEL_IN: R28.1, U5.5 (A3); also elsewhere on the board
/Core Logic, Basic Controls/~MCU_IO: U5.6 (A4); also elsewhere on the board
/Core Logic, Basic Controls/~MCU_MSG/BSY_IN: R30.1, U5.8 (A6); also elsewhere on the board
/Core Logic, Basic Controls/~MCU_REQ: U5.4 (A2); also elsewhere on the board
/Core Logic, Basic Controls/~MCU_SD0: U4.11 (B7); also elsewhere on the board
/Core Logic, Basic Controls/~MCU_SD1: U4.12 (B6); also elsewhere on the board
/Core Logic, Basic Controls/~MCU_SD2: U4.13 (B5); also elsewhere on the board
/Core Logic, Basic Controls/~MCU_SD3: U4.14 (B4); also elsewhere on the board
/Core Logic, Basic Controls/~MCU_SD4: U4.15 (B3); also elsewhere on the board
/Core Logic, Basic Controls/~MCU_SD5: U4.16 (B2); also elsewhere on the board
/Core Logic, Basic Controls/~MCU_SD6: U4.17 (B1); also elsewhere on the board
/Core Logic, Basic Controls/~MCU_SD7: U4.18 (B0); also elsewhere on the board
/Core Logic, Basic Controls/~MCU_SDP: R27.2, U6.2; also elsewhere on the board
/Core Logic, Basic Controls/~MCU_SEL_OUT: U7.1; also elsewhere on the board
/Host Interface/SCSI_I/~O: U5.14 (B4); also elsewhere on the board
/Host Interface/SCSI_~ATTN: U5.7 (A5); also elsewhere on the board
/Host Interface/SCSI_~C/D: U5.15 (B3); also elsewhere on the board
/Host Interface/SCSI_~REQ: U5.16 (B2); also elsewhere on the board
/Host Interface/~SCSI_ACK: R25.1, U5.3 (A1); also elsewhere on the board
/Host Interface/~SCSI_BSY: U6.8, U6.12; also elsewhere on the board
/Host Interface/~SCSI_MSG: U5.12 (B6); also elsewhere on the board
/Host Interface/~SCSI_RST: U7.8, U7.12; also elsewhere on the board
/Host Interface/~SCSI_SD0: U4.9 (A7); also elsewhere on the board
/Host Interface/~SCSI_SD1: U4.8 (A6); also elsewhere on the board
/Host Interface/~SCSI_SD2: U4.7 (A5); also elsewhere on the board
/Host Interface/~SCSI_SD3: U4.6 (A4); also elsewhere on the board
/Host Interface/~SCSI_SD4: U4.5 (A3); also elsewhere on the board
/Host Interface/~SCSI_SD5: U4.4 (A2); also elsewhere on the board
/Host Interface/~SCSI_SD6: U4.3 (A1); also elsewhere on the board
/Host Interface/~SCSI_SD7: U4.2 (A0); also elsewhere on the board
/Host Interface/~SCSI_SDP: U6.3, U6.5; also elsewhere on the board
/Host Interface/~SCSI_SEL: U7.3, U7.5; also elsewhere on the board
/SCSI Buffers/~RST_OUT: R7.1, U7.10, U8.4
GND: C21.2, C22.2, C23.2, C24.2, C25.2, C26.2, U4.10 (GND), U4.19 (CE), U5.9 (A7), U5.10 (GND), U5.11 (B7), U6.4, U6.7 (GND), U6.9, U6.13, U7.2, U7.4, U7.7 (GND), U7.9, U7.13, U8.3 (GND); also elsewhere on the board
unnamed: R27.1, U6.6
unnamed: R28.2, U7.6
unnamed: R29.1, U7.11
unnamed: R30.2, U6.11
unnamed: C21.1, R25.2, U5.2 (A0)
unnamed: R26.1, U5.17 (B1)

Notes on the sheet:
Control line buffering
SCSI_RST is typically an input from the bus. In initiator mode, it is allowed to be driven low by the RP2350 via an LVTH125, and will be deasserted once MCU initializes pins after POR.
LVTH125 Power
SCSI bus Wire-OR'ed lines (SEL, BSY, RST) driven by LVTH125s using the enable gate, so as to make the driver go HiZ when line not asserted.
Data line buffering

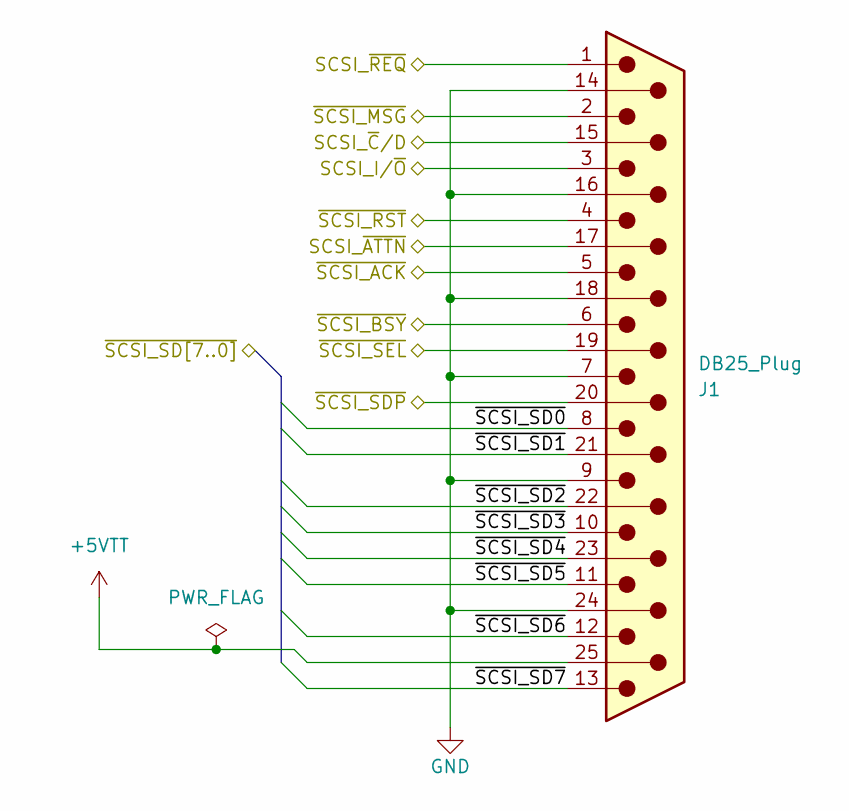
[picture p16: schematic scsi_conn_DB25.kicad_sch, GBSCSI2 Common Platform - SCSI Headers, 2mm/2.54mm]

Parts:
J1: DB25_Plug; DSUB-25_Male_EdgeMount_P2.77mm; LCSC N/A

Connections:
+5VTT: J1.25; also elsewhere on the board
/Host Interface/SCSI_I/~O: J1.3; also elsewhere on the board
/Host Interface/SCSI_~ATTN: J1.17; also elsewhere on the board
/Host Interface/SCSI_~C/D: J1.15; also elsewhere on the board
/Host Interface/SCSI_~REQ: J1.1; also elsewhere on the board
/Host Interface/~SCSI_ACK: J1.5; also elsewhere on the board
/Host Interface/~SCSI_BSY: J1.6; also elsewhere on the board
/Host Interface/~SCSI_MSG: J1.2; also elsewhere on the board
/Host Interface/~SCSI_RST: J1.4; also elsewhere on the board
/Host Interface/~SCSI_SD0: J1.8; also elsewhere on the board
/Host Interface/~SCSI_SD1: J1.21; also elsewhere on the board
/Host Interface/~SCSI_SD2: J1.22; also elsewhere on the board
/Host Interface/~SCSI_SD3: J1.10; also elsewhere on the board
/Host Interface/~SCSI_SD4: J1.23; also elsewhere on the board
/Host Interface/~SCSI_SD5: J1.11; also elsewhere on the board
/Host Interface/~SCSI_SD6: J1.12; also elsewhere on the board
/Host Interface/~SCSI_SD7: J1.13; also elsewhere on the board
/Host Interface/~SCSI_SDP: J1.20; also elsewhere on the board
/Host Interface/~SCSI_SEL: J1.19; also elsewhere on the board
GND: J1.7, J1.9, J1.14, J1.16, J1.18, J1.24; also elsewhere on the board


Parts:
C20, C35: 47μF; C_1206_3216Metric; LCSC C96123
C27: 4.7μF; C_0402_1005Metric; LCSC C23733
C28: 100nF; C_0402_1005Metric; LCSC C307331
C29, C30: 10μF; C_0603_1608Metric; LCSC C96446
C31, C34: 1μF; C_0603_1608Metric; LCSC C15849
C32, C33: 100nF; C_0603_1608Metric; LCSC C14663
D1, D2, D3, D4: 1N5819; D_SOD-123; LCSC C191023
F1, F2: 1A; Fuse_0805_2012Metric; LCSC C468888
J5: Conn_01x04; PinHeader_1x04_P2.54mm_Horizontal; LCSC N/A
JP1, JP2: Jumper_2_Open; PinHeader_2x01_P2.54mm_Vertical; LCSC N/A
L2: 1μH; L_1008_2520Metric; LCSC C5832356
R49: 10kΩ; R_0402_1005Metric; LCSC C25744
R50: 442kΩ; R_0402_1005Metric; LCSC C5101
R51: 100kΩ; R_0402_1005Metric; LCSC C25741
R52: 0Ω; R_0603_1608Metric; LCSC C21189
R53: R_0603_1608Metric; LCSC N/A; not fitted
U9: TLV62569DBV; SOT-23-5; LCSC C141836
U10: AZ1117-2.85; SOT-223-3_TabPin2; LCSC C14791

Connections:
+2.8V: C33.1, C34.1, R53.2, U10.2 (VO); also elsewhere on the board
+3.3V: C28.1, C29.1, C30.1, L2.2, R50.1; also elsewhere on the board
+5V: C20.1, C27.1, C31.1, C32.1, C35.1, F2.2, R49.2, U9.4 (VIN), U10.3 (VI); also elsewhere on the board
+5VIN: D1.2 (A), D4.2 (A), J5.1, JP2.1 (A)
+5VTT: F1.1; also elsewhere on the board
/Power/5V_TIE: D2.1 (K), D3.1 (K), D4.1 (K), F2.1, JP2.2 (B)
GND: C20.2, C27.2, C28.2, C29.2, C30.2, C31.2, C32.2, C33.2, C34.2, C35.2, J5.2, J5.3, R51.2, R52.1, U9.2 (GND); also elsewhere on the board
unnamed: D1.1 (K), JP1.2 (B)
unnamed: D3.2 (A), F1.2, JP1.1 (A)
unnamed: R49.1, U9.1 (EN)
unnamed: R50.2, R51.1, U9.5 (FB)
unnamed: L2.1, U9.3 (SW)
unnamed: R52.2, R53.1, U10.1 (GND)
VBUS: D2.2 (A); also elsewhere on the board

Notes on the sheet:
+2.85V Termination Voltage LDO
+3.3V DC-DC
Bulk Decoupling
Input, Source Switching


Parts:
R31, R32, R33, R34, R35, R36, R37, R38, R39, R40, R41, R42, R43, R44, R45, R46, R47, R48: 110Ω; R_0603_1608Metric; LCSC C22781

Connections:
+2.8V: R31.2, R32.2, R33.2, R34.2, R35.2, R36.2, R37.2, R38.2, R39.2, R40.2, R41.2, R42.2, R43.2, R44.2, R45.2, R46.2, R47.2, R48.2; also elsewhere on the board
/Host Interface/SCSI_I/~O: R48.1; also elsewhere on the board
/Host Interface/SCSI_~ATTN: R40.1; also elsewhere on the board
/Host Interface/SCSI_~C/D: R46.1; also elsewhere on the board
/Host Interface/SCSI_~REQ: R47.1; also elsewhere on the board
/Host Interface/~SCSI_ACK: R42.1; also elsewhere on the board
/Host Interface/~SCSI_BSY: R41.1; also elsewhere on the board
/Host Interface/~SCSI_MSG: R44.1; also elsewhere on the board
/Host Interface/~SCSI_RST: R43.1; also elsewhere on the board
/Host Interface/~SCSI_SD0: R31.1; also elsewhere on the board
/Host Interface/~SCSI_SD1: R32.1; also elsewhere on the board
/Host Interface/~SCSI_SD2: R33.1; also elsewhere on the board
/Host Interface/~SCSI_SD3: R34.1; also elsewhere on the board
/Host Interface/~SCSI_SD4: R35.1; also elsewhere on the board
/Host Interface/~SCSI_SD5: R36.1; also elsewhere on the board
/Host Interface/~SCSI_SD6: R37.1; also elsewhere on the board
/Host Interface/~SCSI_SD7: R38.1; also elsewhere on the board
/Host Interface/~SCSI_SDP: R39.1; also elsewhere on the board
/Host Interface/~SCSI_SEL: R45.1; also elsewhere on the board


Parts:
C7: 10μF; C_0603_1608Metric; LCSC C96446
J2: TF003; TF01A; LCSC C5155563
R18, R19, R20, R21, R22: 4.7kΩ; R_0603_1608Metric; LCSC C23162

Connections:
+3.3V: C7.1, J2.4 (VDD), R18.2, R19.2, R20.2, R21.2, R22.2; also elsewhere on the board
/Core Logic, Basic Controls/SDIO_CLK: J2.5 (CLK); also elsewhere on the board
/Core Logic, Basic Controls/SDIO_CMD: J2.3 (CMD/DI), R20.1; also elsewhere on the board
/Core Logic, Basic Controls/SDIO_D0: J2.7 (DAT0/DO), R21.1; also elsewhere on the board
/Core Logic, Basic Controls/SDIO_D1: J2.8 (DAT1/NC), R22.1; also elsewhere on the board
/Core Logic, Basic Controls/SDIO_D2: J2.1 (DAT2/NC), R18.1; also elsewhere on the board
/Core Logic, Basic Controls/SDIO_D3: J2.2 (DAT3/CS), R19.1; also elsewhere on the board
GND: C7.2, J2.6 (GND), J2.CD1, J2.MP1, J2.MP2, J2.MP3, J2.MP4; also elsewhere on the board


Board: 4 copper layers, 53.0 x 31.0 mm, 90 parts (1 on the bottom side), 69 nets.

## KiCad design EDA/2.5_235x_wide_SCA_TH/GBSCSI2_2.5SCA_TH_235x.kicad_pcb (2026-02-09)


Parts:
FID1, FID2, FID3: Fiducial; Fiducial_0.5mm_Mask1mm; LCSC N/A
J7: Conn_01x05; PinSocket_1x05_P2.54mm_Vertical
PCB1: 2.5" PCB; GBSCSI2_2.5_PCB
R68, R69, R70: 4.7kΩ; R_0402_1005Metric; LCSC C25900

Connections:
+3.3V: J7.1, R68.2, R69.2; also elsewhere on the board
/Core Logic, Basic Controls/I²C_INT: R70.2; also elsewhere on the board
/Core Logic, Basic Controls/I²C_SCL: J7.3, R69.1; also elsewhere on the board
/Core Logic, Basic Controls/I²C_SDA: J7.2, R68.1; also elsewhere on the board
GND: J7.4, R70.1; also elsewhere on the board

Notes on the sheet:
Mechanicals


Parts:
M1: RPi_RM2; LCSC N/A
R54: 10kΩ; R_0402_1005Metric; LCSC C25744
R56: 470Ω; R_0402_1005Metric

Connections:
+3.3V: M1.B7 (VDDIO), M1.C2 (VDDBAT); also elsewhere on the board
/Core Logic, Basic Controls/WL_DAT/~IRQ: M1.A5 (DI), R54.2, R56.2; also elsewhere on the board
/Core Logic, Basic Controls/WL_SCK: M1.A3 (SCLK); also elsewhere on the board
/Core Logic, Basic Controls/~WL_CS: M1.B2 (CS); also elsewhere on the board
/Core Logic, Basic Controls/~WL_EN: M1.B5 (WLON), M1.B6 (BTON); also elsewhere on the board
GND: M1.A1 (GND), M1.A4 (GND), M1.A7 (GND), M1.B4 (GND), M1.C1 (GND), M1.C7 (GND); also elsewhere on the board
unnamed: M1.A6 (DO), R56.1
unnamed: M1.B3 (IRQ), R54.1


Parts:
C1, C4: 4.7μF; C_0603_1608Metric; LCSC C19666
C2, C3: 22pF; C_0402_1005Metric; LCSC C1555
C5: 4.7μF; C_0402_1005Metric; LCSC C23733
C6: 100nF; C_0402_1005Metric; LCSC C307331
D5: YELLOW; LED_0603_1608Metric; LCSC C72038
J4: SM03B-SRSS-TB; JST_SH_SM03B-SRSS-TB_1x03-1MP_P1.00mm_Horizontal; LCSC C160403
J4.1: Conn_01x04; PinHeader_1x04_P2.54mm_Vertical; LCSC N/A
J6, J8: Conn_01x02; PinHeader_1x02_P2.54mm_Vertical; LCSC N/A
L1: 3.3μH; L_Abracon_AOTA-B2016; LCSC C42411119
R1, R4: 1kΩ; R_0402_1005Metric; LCSC C11702
R2: 4.7kΩ; R_0402_1005Metric; LCSC C25900
R3, R15, R16: 22Ω; R_0402_1005Metric; LCSC C25092
R6, R8, R9, R10, R57, R58, R59, R66: 4.7kΩ; R_0603_1608Metric; LCSC C23162
R13, R14, R55: 1kΩ; R_0603_1608Metric; LCSC C21190
SW2: SW_DIP_x03; SW_DIP_SPSTx03_Slide_6.7x9.18mm_W8.61mm_P2.54mm_LowProfile; LCSC C2842910
SW3: GT-TC108A-H034-L1S; SW_Push_1P1T-MP_NO_Horizontal_Alps_SKRTLAE010
U1: RP2350_80QFN; RP2350-QFN-80-1EP_10x10_P0.4mm_EP3.4x3.4mm_ThermalVias; LCSC Part # C42415655
U2: W25Q128JVS; SOIC-8_5.23x5.23mm_P1.27mm; LCSC C97521
Y1: 12MHz; Crystal_SMD_3225-4Pin_3.2x2.5mm; LCSC C133334

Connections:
+1.1V: C4.1, L1.1, U1.10 (DVDD), U1.32 (DVDD), U1.51 (DVDD), U1.65 (VREG_FB); also elsewhere on the board
+2.8V: R6.1, R8.1, R58.1, R59.1; also elsewhere on the board
+3.3V: C1.1, C6.1, J4.1.1, R2.2, R3.2, R13.1, R14.1, R66.1, U1.5 (IOVDD), U1.15 (IOVDD), U1.24 (IOVDD), U1.29 (IOVDD), U1.41 (IOVDD), U1.50 (IOVDD), U1.59 (ADC_AVDD), U1.60 (IOVDD), U1.64 (VREG_VIN), U1.68 (USB_OTP_VDD), U1.69 (QSPI_IOVDD), U1.76 (IOVDD), U2.8 (VCC); also elsewhere on the board
/Core Logic, Basic Controls/ACTY: D5.1 (K), J6.2, R55.1
/Core Logic, Basic Controls/BUS_DIR: R57.2, U1.23 (GPIO23); also elsewhere on the board
/Core Logic, Basic Controls/D+: R15.1; also elsewhere on the board
/Core Logic, Basic Controls/D-: R16.1; also elsewhere on the board
/Core Logic, Basic Controls/EJECT: J8.2, R66.2, SW3.1 (A), U1.55 (GPIO44_ADC4)
/Core Logic, Basic Controls/I²C_INT: U1.37 (GPIO29); also elsewhere on the board
/Core Logic, Basic Controls/I²C_SCL: U1.39 (GPIO31); also elsewhere on the board
/Core Logic, Basic Controls/I²C_SDA: U1.38 (GPIO30); also elsewhere on the board
/Core Logic, Basic Controls/LED_OUT: D5.2 (A), J6.1, U1.42 (GPIO33)
/Core Logic, Basic Controls/QSPI_SCLK: U1.71 (QSPI_SCLK), U2.6 (CLK)
/Core Logic, Basic Controls/QSPI_SD0: U1.72 (QSPI_SD0), U2.5 (DI/IO_{0})
/Core Logic, Basic Controls/QSPI_SD1: U1.74 (QSPI_SD1), U2.2 (DO/IO_{1})
/Core Logic, Basic Controls/QSPI_SD2: U1.73 (QSPI_SD2), U2.3 (~WP/IO_{2})
/Core Logic, Basic Controls/QSPI_SD3: U1.70 (QSPI_SD3), U2.7 (~HOLD/~RESET/IO_{3})
/Core Logic, Basic Controls/QSPI_~SS: R1.1, R2.1, U1.75 (QSPI_SS), U2.1 (~CS)
/Core Logic, Basic Controls/SDIO_CLK: U1.43 (GPIO34); also elsewhere on the board
/Core Logic, Basic Controls/SDIO_CMD: U1.44 (GPIO35); also elsewhere on the board
/Core Logic, Basic Controls/SDIO_D0: U1.45 (GPIO36); also elsewhere on the board
/Core Logic, Basic Controls/SDIO_D1: U1.46 (GPIO37); also elsewhere on the board
/Core Logic, Basic Controls/SDIO_D2: U1.47 (GPIO38); also elsewhere on the board
/Core Logic, Basic Controls/SDIO_D3: U1.48 (GPIO39); also elsewhere on the board
/Core Logic, Basic Controls/SWCLK: J4.1, J4.1.3, U1.33 (SWCLK)
/Core Logic, Basic Controls/SWD: J4.3, J4.1.2, U1.34 (SWDIO)
/Core Logic, Basic Controls/USB_D+: R15.2, U1.67 (USB_DP)
/Core Logic, Basic Controls/USB_D-: R16.2, U1.66 (USB_DM)
/Core Logic, Basic Controls/VREG_LX: L1.2, U1.63 (VREG_LX)
/Core Logic, Basic Controls/WL_DAT/~IRQ: U1.52 (GPIO41_ADC1); also elsewhere on the board
/Core Logic, Basic Controls/WL_SCK: U1.54 (GPIO43_ADC3); also elsewhere on the board
/Core Logic, Basic Controls/XIN: C2.1, U1.30 (XIN), Y1.3
/Core Logic, Basic Controls/XOUT: R4.1, U1.31 (XOUT)
/Core Logic, Basic Controls/~DEBUG: R10.2, U1.40 (GPIO32)
/Core Logic, Basic Controls/~INITIATOR: R9.1, R14.2, SW2.6; also elsewhere on the board
/Core Logic, Basic Controls/~MCU_ACK: R9.2, U1.28 (GPIO27); also elsewhere on the board
/Core Logic, Basic Controls/~MCU_ATTN: U1.26 (GPIO25); also elsewhere on the board
/Core Logic, Basic Controls/~MCU_BSY_OUT: R6.2, U1.78 (GPIO1); also elsewhere on the board
/Core Logic, Basic Controls/~MCU_CD/SEL_IN: U1.25 (GPIO24); also elsewhere on the board
/Core Logic, Basic Controls/~MCU_IO: U1.36 (GPIO28); also elsewhere on the board
/Core Logic, Basic Controls/~MCU_MSG/BSY_IN: U1.27 (GPIO26); also elsewhere on the board
/Core Logic, Basic Controls/~MCU_REQ: R58.2, U1.22 (GPIO22); also elsewhere on the board
/Core Logic, Basic Controls/~MCU_RST_IN: U1.79 (GPIO2); also elsewhere on the board
/Core Logic, Basic Controls/~MCU_RST_OUT: R59.2, U1.80 (GPIO3); also elsewhere on the board
/Core Logic, Basic Controls/~MCU_SD0: U1.1 (GPIO4); also elsewhere on the board
/Core Logic, Basic Controls/~MCU_SD1: U1.2 (GPIO5); also elsewhere on the board
/Core Logic, Basic Controls/~MCU_SD2: U1.3 (GPIO6); also elsewhere on the board
/Core Logic, Basic Controls/~MCU_SD3: U1.4 (GPIO7); also elsewhere on the board
/Core Logic, Basic Controls/~MCU_SD4: U1.6 (GPIO8); also elsewhere on the board
/Core Logic, Basic Controls/~MCU_SD5: U1.7 (GPIO9); also elsewhere on the board
/Core Logic, Basic Controls/~MCU_SD6: U1.8 (GPIO10); also elsewhere on the board
/Core Logic, Basic Controls/~MCU_SD7: U1.9 (GPIO11); also elsewhere on the board
/Core Logic, Basic Controls/~MCU_SD8: U1.11 (GPIO12); also elsewhere on the board
/Core Logic, Basic Controls/~MCU_SD9: U1.12 (GPIO13); also elsewhere on the board
/Core Logic, Basic Controls/~MCU_SD10: U1.13 (GPIO14); also elsewhere on the board
/Core Logic, Basic Controls/~MCU_SD11: U1.14 (GPIO15); also elsewhere on the board
/Core Logic, Basic Controls/~MCU_SD12: U1.16 (GPIO16); also elsewhere on the board
/Core Logic, Basic Controls/~MCU_SD13: U1.17 (GPIO17); also elsewhere on the board
/Core Logic, Basic Controls/~MCU_SD14: U1.18 (GPIO18); also elsewhere on the board
/Core Logic, Basic Controls/~MCU_SD15: U1.19 (GPIO19); also elsewhere on the board
/Core Logic, Basic Controls/~MCU_SDP1: U1.21 (GPIO21)
/Core Logic, Basic Controls/~MCU_SDP: U1.20 (GPIO20)
/Core Logic, Basic Controls/~MCU_SEL_OUT: R8.2, U1.77 (GPIO0); also elsewhere on the board
/Core Logic, Basic Controls/~USB_BOOT: R1.2, SW2.4
/Core Logic, Basic Controls/~WL_CS: U1.53 (GPIO42_ADC2); also elsewhere on the board
/Core Logic, Basic Controls/~WL_EN: U1.49 (GPIO40_ADC0); also elsewhere on the board
GND: C1.2, C2.2, C3.2, C4.2, C5.2, C6.2, J4.2, J4.1.4, J8.1, R55.2, R57.1, SW2.1, SW2.2, SW2.3, SW3.2 (B), U1.62 (VREG_PGND), U1.81 (GND), U2.4 (GND), Y1.2, Y1.4; also elsewhere on the board
unnamed: C3.1, R4.2, Y1.1
unnamed: R10.1, R13.2, SW2.5
unnamed: C5.1, R3.1, U1.61 (VREG_AVDD)

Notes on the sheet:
128Mb NOR Flash
Pull-ups for MCU-side SCSI bus Wire-OR'ed lines and data lines' buffer direction control.
IF 2354, DNF U2
MCU and ancillaries
REQ pulled high - no termination on SCA
Make sure R15 and R16 are close to RP2350
Meets revised Pi VREG guidelines


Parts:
C21: 12pF; C_0603_1608Metric; LCSC C38523
C22, C23, C25, C26, C41: 100nF; C_0603_1608Metric; LCSC C14663
C42: 100nF; C_0402_1005Metric; LCSC C1525
R25: 110Ω; R_0603_1608Metric; LCSC C22781
R26, R28, R30: 1kΩ; R_0603_1608Metric; LCSC C21190
U4, U5, U12: 74LVTH245; SSOP-20_5.3x7.2mm_P0.65mm; LCSC C2652121
U6, U7: 74LVTH125; TSSOP-14_4.4x5mm_P0.65mm; LCSC C7042
U13: 74LVCH2T45; LCSC C5916231

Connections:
+2.8V: C22.1, C23.1, C25.1, C26.1, C41.1, C42.1, U4.20 (VCC), U5.20 (VCC), U6.14 (VCC), U7.14 (VCC), U12.20 (VCC), U13.1 (VCCA), U13.8 (VCCB); also elsewhere on the board
/Core Logic, Basic Controls/BUS_DIR: U4.1 (A->B), U12.1 (A->B), U13.5 (DIR); also elsewhere on the board
/Core Logic, Basic Controls/~INITIATOR: U5.1 (A->B); also elsewhere on the board
/Core Logic, Basic Controls/~MCU_ACK: R26.2, U5.18 (B0); also elsewhere on the board
/Core Logic, Basic Controls/~MCU_ATTN: U5.13 (B5); also elsewhere on the board
/Core Logic, Basic Controls/~MCU_BSY_OUT: U5.19 (CE), U6.10; also elsewhere on the board
/Core Logic, Basic Controls/~MCU_CD/SEL_IN: R28.1, U5.5 (A3); also elsewhere on the board
/Core Logic, Basic Controls/~MCU_IO: U5.6 (A4); also elsewhere on the board
/Core Logic, Basic Controls/~MCU_MSG/BSY_IN: R30.1, U5.8 (A6); also elsewhere on the board
/Core Logic, Basic Controls/~MCU_REQ: U5.4 (A2); also elsewhere on the board
/Core Logic, Basic Controls/~MCU_RST_IN: U6.6; also elsewhere on the board
/Core Logic, Basic Controls/~MCU_RST_OUT: U6.1; also elsewhere on the board
/Core Logic, Basic Controls/~MCU_SD0: U4.2 (A0); also elsewhere on the board
/Core Logic, Basic Controls/~MCU_SD1: U4.3 (A1); also elsewhere on the board
/Core Logic, Basic Controls/~MCU_SD2: U4.4 (A2); also elsewhere on the board
/Core Logic, Basic Controls/~MCU_SD3: U4.5 (A3); also elsewhere on the board
/Core Logic, Basic Controls/~MCU_SD4: U4.6 (A4); also elsewhere on the board
/Core Logic, Basic Controls/~MCU_SD5: U4.7 (A5); also elsewhere on the board
/Core Logic, Basic Controls/~MCU_SD6: U4.8 (A6); also elsewhere on the board
/Core Logic, Basic Controls/~MCU_SD7: U4.9 (A7); also elsewhere on the board
/Core Logic, Basic Controls/~MCU_SD8: U12.2 (A0); also elsewhere on the board
/Core Logic, Basic Controls/~MCU_SD9: U12.3 (A1); also elsewhere on the board
/Core Logic, Basic Controls/~MCU_SD10: U12.4 (A2); also elsewhere on the board
/Core Logic, Basic Controls/~MCU_SD11: U12.5 (A3); also elsewhere on the board
/Core Logic, Basic Controls/~MCU_SD12: U12.6 (A4); also elsewhere on the board
/Core Logic, Basic Controls/~MCU_SD13: U12.7 (A5); also elsewhere on the board
/Core Logic, Basic Controls/~MCU_SD14: U12.8 (A6); also elsewhere on the board
/Core Logic, Basic Controls/~MCU_SD15: U12.9 (A7); also elsewhere on the board
/Core Logic, Basic Controls/~MCU_SEL_OUT: U7.4; also elsewhere on the board
/Host Interface/SCSI_I/~O: U5.14 (B4); also elsewhere on the board
/Host Interface/SCSI_~ATTN: U5.7 (A5); also elsewhere on the board
/Host Interface/SCSI_~C/D: U5.15 (B3); also elsewhere on the board
/Host Interface/SCSI_~REQ: U5.16 (B2); also elsewhere on the board
/Host Interface/~SCSI_ACK: R25.1, U5.3 (A1); also elsewhere on the board
/Host Interface/~SCSI_BSY: U6.8, U6.12; also elsewhere on the board
/Host Interface/~SCSI_MSG: U5.12 (B6); also elsewhere on the board
/Host Interface/~SCSI_RST: U6.3, U6.5; also elsewhere on the board
/Host Interface/~SCSI_SD0: U4.18 (B0); also elsewhere on the board
/Host Interface/~SCSI_SD1: U4.17 (B1); also elsewhere on the board
/Host Interface/~SCSI_SD2: U4.16 (B2); also elsewhere on the board
/Host Interface/~SCSI_SD3: U4.15 (B3); also elsewhere on the board
/Host Interface/~SCSI_SD4: U4.14 (B4); also elsewhere on the board
/Host Interface/~SCSI_SD5: U4.13 (B5); also elsewhere on the board
/Host Interface/~SCSI_SD6: U4.12 (B6); also elsewhere on the board
/Host Interface/~SCSI_SD7: U4.11 (B7); also elsewhere on the board
/Host Interface/~SCSI_SD8: U12.18 (B0); also elsewhere on the board
/Host Interface/~SCSI_SD9: U12.17 (B1); also elsewhere on the board
/Host Interface/~SCSI_SD10: U12.16 (B2); also elsewhere on the board
/Host Interface/~SCSI_SD11: U12.15 (B3); also elsewhere on the board
/Host Interface/~SCSI_SD12: U12.14 (B4); also elsewhere on the board
/Host Interface/~SCSI_SD13: U12.13 (B5); also elsewhere on the board
/Host Interface/~SCSI_SD14: U12.12 (B6); also elsewhere on the board
/Host Interface/~SCSI_SD15: U12.11 (B7); also elsewhere on the board
/Host Interface/~SCSI_SEL: U7.2, U7.6; also elsewhere on the board
GND: C21.2, C22.2, C23.2, C25.2, C26.2, C41.2, C42.2, U4.10 (GND), U4.19 (CE), U5.9 (A7), U5.10 (GND), U5.11 (B7), U6.2, U6.4, U6.7 (GND), U6.9, U6.13, U7.1, U7.5, U7.7 (GND), U7.9, U7.10, U7.12, U7.13, U12.10 (GND), U12.19 (CE), U13.4 (GND); also elsewhere on the board
unnamed: R28.2, U7.3
unnamed: R30.2, U6.11
unnamed: C21.1, R25.2, U5.2 (A0)
unnamed: R26.1, U5.17 (B1)

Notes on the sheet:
Control line buffering
SCSI_RST is typically an input from the bus. In initiator mode, it is allowed to be driven low by the RP2350 via an LVTH125, and will be deasserted once MCU initializes pins after POR.
LVTH125 Power
SCSI bus Wire-OR'ed lines (SEL, BSY, RST) driven by LVTH125s using the enable gate, so as to make the driver go HiZ when line not asserted.
Spare Gates
Data Parity line buffering
Data line buffering


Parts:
J1: Conn_02x40_Counter_Clockwise; CHAMPII_80
R63, R67: 10k; R_0603_1608Metric; LCSC C25804; not fitted

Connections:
+5VIN: J1.34, J1.35, J1.36, R63.2, R67.2; also elsewhere on the board
/Host Interface/ACTY: J1.77
/Host Interface/SCSI_I/~O: J1.11; also elsewhere on the board
/Host Interface/SCSI_~ATTN: J1.19; also elsewhere on the board
/Host Interface/SCSI_~C/D: J1.13; also elsewhere on the board
/Host Interface/SCSI_~REQ: J1.12; also elsewhere on the board
/Host Interface/~SCSI_ACK: J1.17; also elsewhere on the board
/Host Interface/~SCSI_BSY: J1.18; also elsewhere on the board
/Host Interface/~SCSI_MSG: J1.15; also elsewhere on the board
/Host Interface/~SCSI_RST: J1.16; also elsewhere on the board
/Host Interface/~SCSI_SD0: J1.28; also elsewhere on the board
/Host Interface/~SCSI_SD1: J1.27; also elsewhere on the board
/Host Interface/~SCSI_SD2: J1.26; also elsewhere on the board
/Host Interface/~SCSI_SD3: J1.25; also elsewhere on the board
/Host Interface/~SCSI_SD4: J1.24; also elsewhere on the board
/Host Interface/~SCSI_SD5: J1.23; also elsewhere on the board
/Host Interface/~SCSI_SD6: J1.22; also elsewhere on the board
/Host Interface/~SCSI_SD7: J1.21; also elsewhere on the board
/Host Interface/~SCSI_SD8: J1.10; also elsewhere on the board
/Host Interface/~SCSI_SD9: J1.9; also elsewhere on the board
/Host Interface/~SCSI_SD10: J1.8; also elsewhere on the board
/Host Interface/~SCSI_SD11: J1.7; also elsewhere on the board
/Host Interface/~SCSI_SD12: J1.33; also elsewhere on the board
/Host Interface/~SCSI_SD13: J1.32; also elsewhere on the board
/Host Interface/~SCSI_SD14: J1.31; also elsewhere on the board
/Host Interface/~SCSI_SD15: J1.30; also elsewhere on the board
/Host Interface/~SCSI_SDP1: J1.29
/Host Interface/~SCSI_SDP: J1.20
/Host Interface/~SCSI_SEL: J1.14; also elsewhere on the board
GND: J1.41, J1.42, J1.43, J1.46, J1.47, J1.48, J1.49, J1.50, J1.51, J1.52, J1.53, J1.54, J1.55, J1.56, J1.57, J1.58, J1.59, J1.60, J1.61, J1.62, J1.63, J1.64, J1.65, J1.66, J1.67, J1.68, J1.69, J1.70, J1.71, J1.72, J1.73, J1.75, J1.76; also elsewhere on the board
unnamed: J1.44, R67.1
unnamed: J1.74, R63.1


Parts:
C20, C35: 47μF; C_1206_3216Metric; LCSC C96123
C27, C37: 4.7μF; C_0402_1005Metric; LCSC C23733
C28, C38: 100nF; C_0402_1005Metric; LCSC C307331
C29, C30, C39, C40: 10μF; C_0603_1608Metric; LCSC C96446
D2, D4: 1N5819; D_SOD-123; LCSC C191023
F2: 1A; Fuse_0805_2012Metric; LCSC C468888
L2, L3: 1μH; L_1008_2520Metric; LCSC C5832356
R49, R60: 10kΩ; R_0402_1005Metric; LCSC C25744
R50: 442kΩ; R_0402_1005Metric; LCSC C5101
R51, R62: 100kΩ; R_0402_1005Metric; LCSC C25741
R61: 374kΩ; R_0402_1005Metric; LCSC C25781
U9, U11: TLV62569DBV; SOT-23-5; LCSC C141836

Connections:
+2.8V: C38.1, C39.1, C40.1, L3.2, R61.1; also elsewhere on the board
+3.3V: C28.1, C29.1, C30.1, L2.2, R50.1; also elsewhere on the board
+5V: C20.1, C27.1, C35.1, C37.1, F2.2, R49.2, R60.2, U9.4 (VIN), U11.4 (VIN)
+5VIN: D4.2 (A); also elsewhere on the board
/Power/5V_TIE: D2.1 (K), D4.1 (K), F2.1
GND: C20.2, C27.2, C28.2, C29.2, C30.2, C35.2, C37.2, C38.2, C39.2, C40.2, R51.2, R62.2, U9.2 (GND), U11.2 (GND); also elsewhere on the board
unnamed: R49.1, U9.1 (EN)
unnamed: R50.2, R51.1, U9.5 (FB)
unnamed: L2.1, U9.3 (SW)
unnamed: R60.1, U11.1 (EN)
unnamed: R61.2, R62.1, U11.5 (FB)
unnamed: L3.1, U11.3 (SW)
VBUS: D2.2 (A); also elsewhere on the board

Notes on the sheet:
+3.3V DC-DC
Bulk Decoupling
Input, Source Switching
2.85V DC-DC


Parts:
C7: 10μF; C_0603_1608Metric; LCSC C96446
J2: TF003; TF01A; LCSC C5155563
R18, R19, R20, R21, R22: 4.7kΩ; R_0603_1608Metric; LCSC C23162

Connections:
+3.3V: C7.1, J2.4 (VDD), R18.2, R19.2, R20.2, R21.2, R22.2; also elsewhere on the board
/Core Logic, Basic Controls/SDIO_CLK: J2.5 (CLK); also elsewhere on the board
/Core Logic, Basic Controls/SDIO_CMD: J2.3 (CMD/DI), R20.1; also elsewhere on the board
/Core Logic, Basic Controls/SDIO_D0: J2.7 (DAT0/DO), R21.1; also elsewhere on the board
/Core Logic, Basic Controls/SDIO_D1: J2.8 (DAT1/NC), R22.1; also elsewhere on the board
/Core Logic, Basic Controls/SDIO_D2: J2.1 (DAT2/NC), R18.1; also elsewhere on the board
/Core Logic, Basic Controls/SDIO_D3: J2.2 (DAT3/CS), R19.1; also elsewhere on the board
GND: C7.2, J2.6 (GND), J2.CD1, J2.MP1, J2.MP2, J2.MP3, J2.MP4; also elsewhere on the board


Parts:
C8: 100nF; C_0402_1005Metric; LCSC C307331
J3: GCT-4105; USB_C_Receptacle_HRO_TYPE-C-31-M-12; LCSC C2927038
R23, R24: 5.1kΩ; R_0402_1005Metric; LCSC C25905
U3: USB TVS; SOT-23-6; LCSC C2827654

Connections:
/Core Logic, Basic Controls/D+: J3.A6 (D+), J3.B6 (D+), U3.3 (I/O2), U3.4 (I/O2); also elsewhere on the board
/Core Logic, Basic Controls/D-: J3.A7 (D-), J3.B7 (D-), U3.1 (I/O1), U3.6 (I/O1); also elsewhere on the board
/Core Logic, Basic Controls/USB/CC1: J3.A5 (CC1), R24.1
/Core Logic, Basic Controls/USB/CC2: J3.B5 (CC2), R23.1
GND: C8.2, J3.A1 (GND), J3.A12 (GND), J3.B1 (GND), J3.B12 (GND), J3.S1 (SHIELD), R23.2, R24.2, U3.2 (GND); also elsewhere on the board
VBUS: C8.1, J3.A4 (VBUS), J3.A9 (VBUS), J3.B4 (VBUS), J3.B9 (VBUS), U3.5 (VBUS); also elsewhere on the board

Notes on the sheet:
USB-C Spec §3.2.1¶11

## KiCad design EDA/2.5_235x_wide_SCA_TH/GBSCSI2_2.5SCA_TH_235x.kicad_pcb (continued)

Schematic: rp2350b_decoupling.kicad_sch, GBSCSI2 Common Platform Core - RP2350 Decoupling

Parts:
C9, C11, C13, C14, C15, C16, C17, C18, C19, C36, C43: 100nF; C_0402_1005Metric; LCSC C307331
C10: 4.7μF; C_0402_1005Metric; LCSC C23733
C12: 1μF; C_0402_1005Metric; LCSC C52923

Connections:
+1.1V: C9.1, C10.1, C11.1; also elsewhere on the board
+3.3V: C12.1, C13.1, C14.1, C15.1, C16.1, C17.1, C18.1, C19.1, C36.1, C43.1; also elsewhere on the board
GND: C9.2, C10.2, C11.2, C12.2, C13.2, C14.2, C15.2, C16.2, C17.2, C18.2, C19.2, C36.2, C43.2; also elsewhere on the board


Board: 4 copper layers, 69.5 x 93.5 mm, 112 parts (1 on the bottom side), 113 nets.

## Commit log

2024-03-27 Initial file addition
    [GBSCSI_3.5_SMD_bom_1117_285.csv, GBSCSI_3.5_SMD_bom_1117_adj.csv, GBSCSI_3.5_SMD_placements.csv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]
2024-04-06 Added Pico populating info
2024-04-23 Corrected wrong keying on 2.5" connector
    [gbscsi2.kicad_pcb]
2024-08-08 added WIP RP2350 variant
    [gbscsi2.kicad_pcb, gbscsi2.kicad_sch]
2024-08-30 Changed diodes in BoM, minor corrections to PCB, documentation
    [GBSCSI_3.5_SMD_bom_1117_285.csv, GBSCSI_3.5_SMD_bom_1117_adj.csv, GBSCSI_DB25_SMD_bom.csv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]
2024-10-04 BoM fixes for discrete variants, interactive BoMs added to each major type, mfg files for 2350
    [GBSCSI_hyb2350_bom.csv, GBSCSI_hyb2350_placement.csv, gbscsi2.kicad_pcb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]
2024-10-04 Corrected U9 rotation
    [GBSCSI_hyb2350_placement.csv]
2024-10-27 moving RP2350 to full release
    [GBSCSI_hyb2350_bom.csv, GBSCSI_hyb2350_placement.csv, gbscsi2.kicad_pcb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]
2024-10-27 I screwed up the readme, lol
2025-01-02 Added FreeCAD version of drive tray and updated readme to relect purchasing from Emmy Bear Retro's tindie
    [GBSCSI2_OS.FCStd]
2025-02-15 Added jank FWSCSI variant
    Just a test board.
    [gbscsi2.kicad_sch]
2025-03-09 Redoing Wide variant - WIP
    [gbscsi2.kicad_sch]
2025-03-09 Added SCA variant
    [gbscsi2.kicad_pcb, gbscsi2.kicad_sch]
2025-03-09 Re-sorting things around
    [GBSCSI_hyb2350_bom.csv, GBSCSI_hyb2350_placement.csv, bom.csv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]
2025-03-09 Attempting to organize sheet details, adding eject buttons to Wide variants
    [gbscsi2.kicad_pcb, gbscsi2.kicad_sch]
2025-03-10 Cleaning up, updating docs
    [GBSCSI_3.5_SMD_bom_1117_285.csv, GBSCSI_3.5_SMD_bom_1117_adj.csv, GBSCSI_DB25_SMD_bom.csv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]
2025-03-16 Minor BoM fixes, added left-behind HD68 variant eject switch
    [GBSCSI_hyb2350_bom.csv, bom.csv, designators.csv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]
2026-02-04 Archiving old versions, migrating project to fresh redesign - WIP
    See readme. Premade assembly files for new versions not yet available. BoM and DRC still need some fettling.
    [GBSCSI2_2.5N_235x.kicad_pcb, GBSCSI2_2.5N_235x.kicad_sch, GBSCSI2_2.5N_Pico.kicad_pcb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]
2026-02-04 Started work on thru-hole SCA wide variant
    [GBSCSI2_2.5SCA_TH_235x.kicad_pcb, GBSCSI2_2.5SCA_TH_235x.kicad_sch, buffers_narrow.kicad_sch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]
2026-02-04 Fixing up schematics for SCA before layout
    [GBSCSI2_2.5SCA_TH_235x.kicad_sch, buffers_wide.kicad_sch, core_235xB_wide.kicad_sch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]
2026-02-04 SCA variant mostly laid out
    Or rather, a first pass.
    [GBSCSI2_2.5SCA_TH_235x.kicad_pcb, buffers_wide.kicad_sch, core_235xB_wide.kicad_sch]
2026-02-08 Tidying up PCB footprint slightly, more work needed, ERC passes on narrow variants
    [GBSCSI2_2.5N_235x.kicad_pcb, GBSCSI2_2.5N_Pico.kicad_pcb, GBSCSI2_2.5SCA_TH_235x.kicad_pcb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]
2026-02-08 Prettifying models
    [GBSCSI2_2.5N_235x.kicad_pcb, GBSCSI2_2.5N_Pico.kicad_pcb, GBSCSI2_2.5SCA_TH_235x.kicad_pcb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]
2026-02-09 Fixing PCB footprint
    [GBSCSI2_2.5N_235x.kicad_pcb, GBSCSI2_2.5N_Pico.kicad_pcb, GBSCSI2_2.5SCA_TH_235x.kicad_pcb]
2026-05-11 Resuming work
    [GBSCSI2_2.5N_235x.kicad_pcb, GBSCSI2_DB25_2354A.kicad_pcb, GBSCSI2_DB25_2354A.kicad_sch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]
2026-05-12 Minor tweaks
    [GBSCSI2_2.5N_235x.kicad_pcb, core_235xA_narrow.kicad_sch]

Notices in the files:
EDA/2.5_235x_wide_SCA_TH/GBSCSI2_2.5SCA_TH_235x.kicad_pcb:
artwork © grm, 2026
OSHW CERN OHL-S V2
